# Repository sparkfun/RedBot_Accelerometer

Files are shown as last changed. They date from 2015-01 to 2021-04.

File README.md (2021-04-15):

RedBot Accelerometer
==================
SparkFun RedBot Accelerometer (https://www.sparkfun.com/products/12589)

[*SparkFun RedBot Accelerometer*](https://www.sparkfun.com/products/12589)

The accelerometer sensor is an add-on for the RedBot kit that provides bump and motion detection. 
It is an I<sup>2</sup>C, and is a 3-axis sensor.

Repository Contents
-------------------

* **/Hardware** - Eagle PCB layout files
* **/Production** - Pogo testbed files

Documentation
-------------------
* **[Assembly Guide for RedBot with Shadow Chassis](https://learn.sparkfun.com/tutorials/assembly-guide-for-redbot-with-shadow-chassis)**
* **[Experiment Guide for RedBot with Shadow Chassis](https://learn.sparkfun.com/tutorials/experiment-guide-for-redbot-with-shadow-chassis)**

License Information
-------------------

The hardware is released under [Creative Commons ShareAlike 4.0 International](https://creativecommons.org/licenses/by-sa/4.0/).
The code is beerware; if you see me (or any other SparkFun employee) at the local, and you've found our code helpful, please buy us a round!

Distributed as-is; no warranty is given.

Authors: Mike Hord @ SparkFun Electonics

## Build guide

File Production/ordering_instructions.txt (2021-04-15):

panel size, 115x171mm
PCB thickness, 1.6mm
number of layers, 2
soldermask color, Red
silkscreen color, White
oz copper, 1oz
finish, HASL lead free
stencils, top
pcs per panel, 63
min trace width, 0.1778mm / 0.0070in
min drill size, 0.3810mm / 0.0150in

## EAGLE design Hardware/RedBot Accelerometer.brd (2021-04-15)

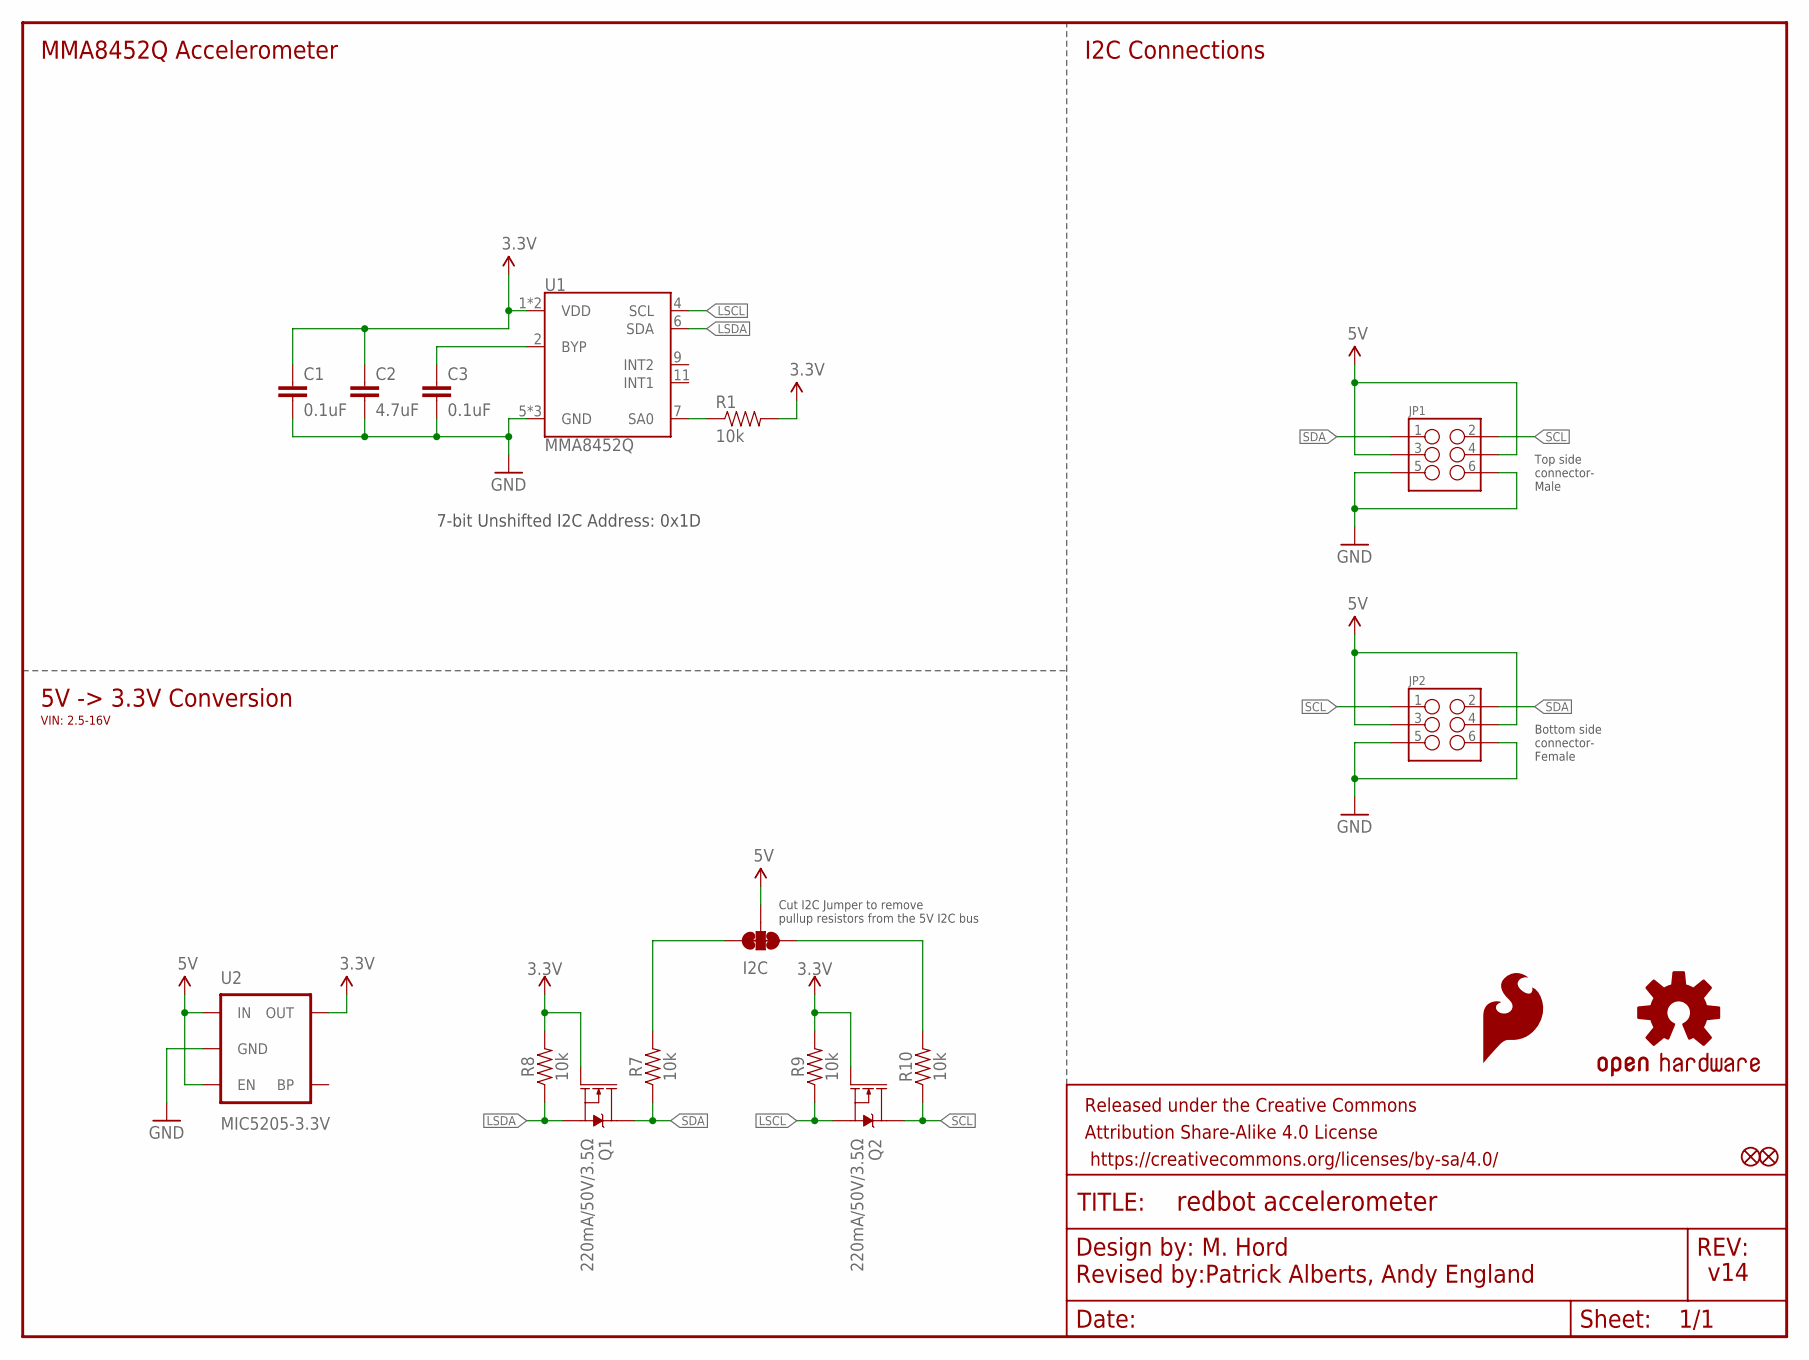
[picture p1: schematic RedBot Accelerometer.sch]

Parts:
C1, C3: 0.1uF; 0603
C2: 4.7uF; 0603
FID1, FID3: FIDUCIAL1X2; FIDUCIAL-1X2
FRAME1: FRAME-LETTER; CREATIVE_COMMONS
I2C: JUMPER-SMT_3_2-NC_TRACE_SILK; SMT-JUMPER_3_2-NC_TRACE_SILK
JP1: M03X2SMT; 2X3_SMT_POSTS
JP2: M03X2FEMALE_SMD; 2X3_SMD
LOGO2: OSHW-LOGOS; OSHW-LOGO-S
LOGO4: SFE_LOGO_FLAME.1_INCH; SFE_LOGO_FLAME_.1
Q1, Q2: 220mA/50V/3.5Ω; SOT23-3
R1, R7, R8, R9, R10: 10k; 0603
U1: MMA8452Q; QFN-16
U2: MIC5205-3.3V; SOT23-5

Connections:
3.3V: C1.1, C2.1, Q1.1 (G), Q2.1 (G), R1.2, R8.2, R9.2, U1.1 (VDD), U1.14 (VDD), U2.5 (OUT)
5V: I2C.2, JP1.3, JP1.4, JP2.3, JP2.4, U2.1 (IN), U2.3 (EN)
ADDR: R1.1, U1.7 (SA0)
GND: C1.2, C2.2, C3.2, JP1.5, JP1.6, JP2.5, JP2.6, U1.5 (GND), U1.10 (GND), U1.12 (GND), U2.2 (GND)
LSCL: Q2.2 (S), R9.1, U1.4 (SCL)
LSDA: Q1.2 (S), R8.1, U1.6 (SDA)
unnamed: C3.1, U1.2 (BYP)
unnamed: I2C.3, R7.2
unnamed: I2C.1, R10.2
SCL: JP1.2, JP2.1, Q2.3 (D), R10.1
SDA: JP1.1, JP2.2, Q1.3 (D), R7.1

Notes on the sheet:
v14
M. Hord
Top side connector- Male
Bottom side connector- Female
Revised by:Patrick Alberts, Andy England
Cut I2C Jumper to remove pullup resistors from the 5V I2C bus
5V -> 3.3V Conversion
MMA8452Q Accelerometer
I2C Connections
VIN: 2.5-16V
7-bit Unshifted I2C Address: 0x1D

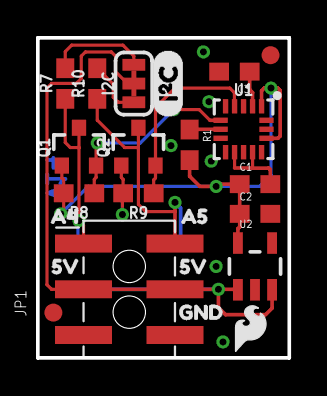
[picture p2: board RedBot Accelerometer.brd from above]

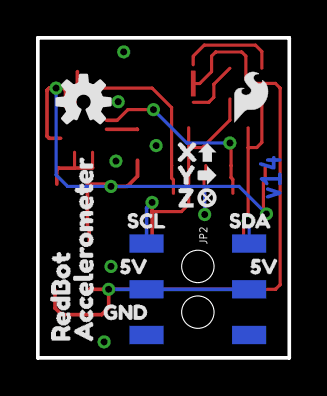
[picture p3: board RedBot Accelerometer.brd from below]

Board: 2 copper layers, 14.0 x 17.8 mm, 39 parts (15 on the bottom side), 11 nets.

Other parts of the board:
LOGO3: LOGO-SFESK; SFE-LOGO-FLAME
U$1: X0
U$2: A42
U$3: A53
U$4, U$5, U$8, U$11: _5V1
U$6, U$7: GND0
U$9: SDA6
U$10: _SCL7
U$12: ##3
U$13: ##4
U$14: Y1
U$15: Z2
U$16: REDBOT4
U$17: ACCELEROMETER5
U$19: I2C

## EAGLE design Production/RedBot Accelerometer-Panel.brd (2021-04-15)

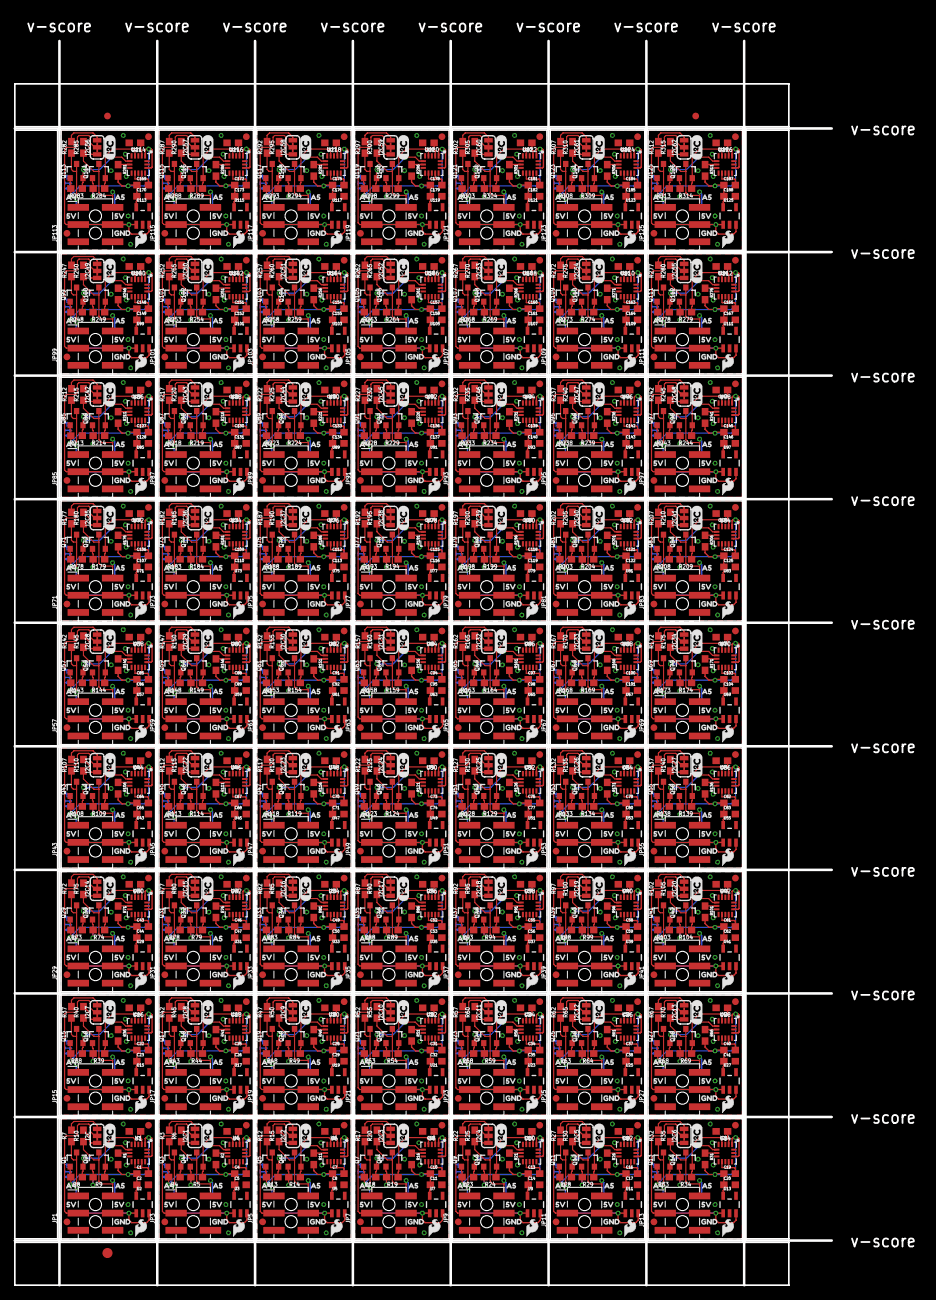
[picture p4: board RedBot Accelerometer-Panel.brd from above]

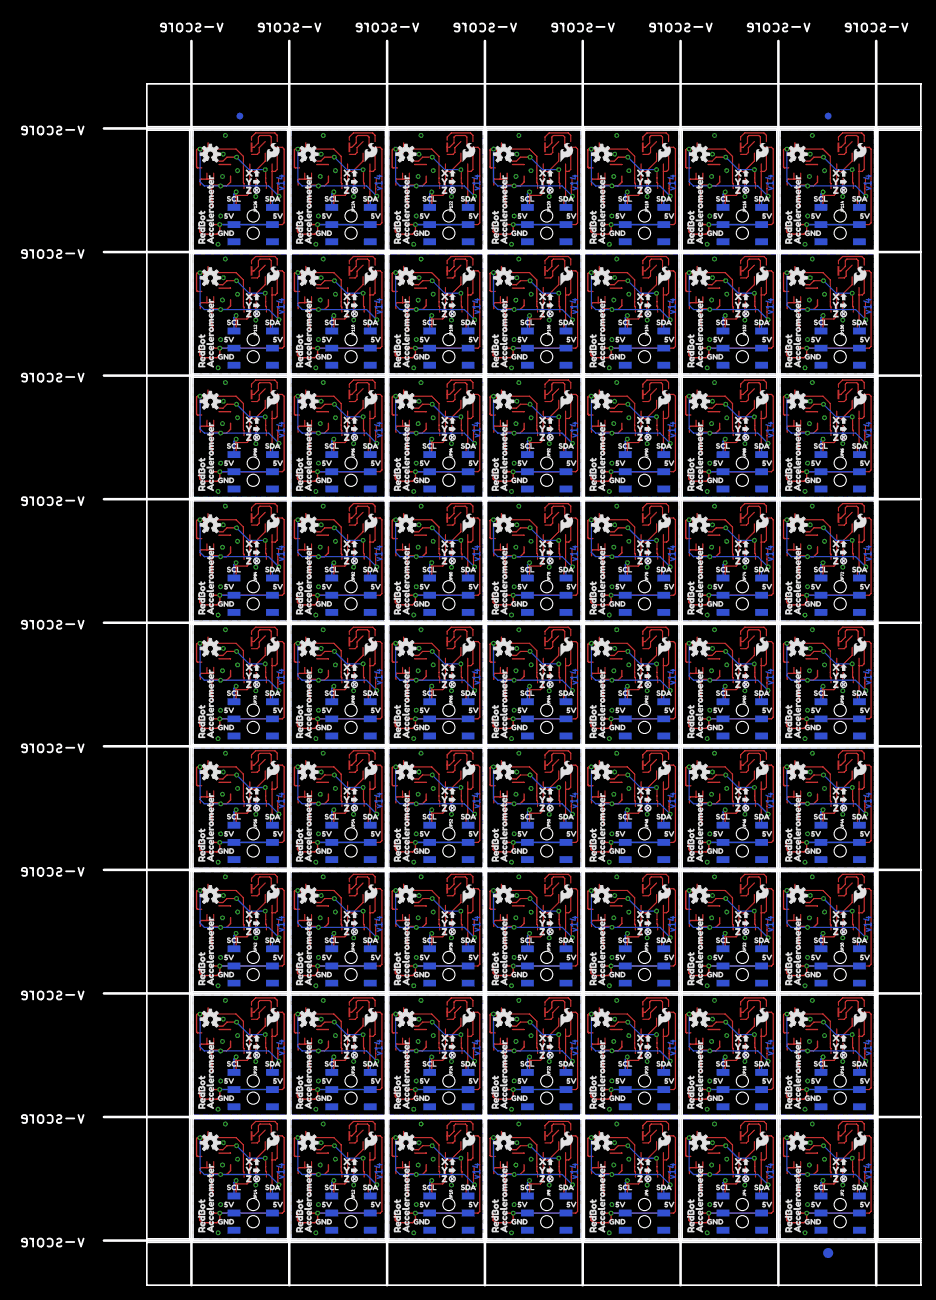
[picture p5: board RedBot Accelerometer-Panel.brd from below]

Board: 2 copper layers, 120.9 x 184.2 mm, 2400 parts (948 on the bottom side), 693 nets.

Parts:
C1, C3, C4, C6, C7, C9, C10, C12, C13, C15, C16, C18, C19, C21, C22, C24, C25, C27, C28, C30, C31, C33, C34, C36, C37, C39, C40, C42, C43, C45, C46, C48, C49, C51, C52, C54, C55, C57, C58, C60, C61, C63, C64, C66, C67, C69, C70, C72, C73, C75, C76, C78, C79, C81, C82, C84, C85, C87, C88, C90, C91, C93, C94, C96, C97, C99, C100, C102, C103, C105, C106, C108, C109, C111, C112, C114, C115, C117, C118, C120, C121, C123, C124, C126, C127, C129, C130, C132, C133, C135, C136, C138, C139, C141, C142, C144, C145, C147, C148, C150, C151, C153, C154, C156, C157, C159, C160, C162, C163, C165, C166, C168, C169, C171, C172, C174, C175, C177, C178, C180, C181, C183, C184, C186, C187, C189: 0.1uF; 0603
C2, C5, C8, C11, C14, C17, C20, C23, C26, C29, C32, C35, C38, C41, C44, C47, C50, C53, C56, C59, C62, C65, C68, C71, C74, C77, C80, C83, C86, C89, C92, C95, C98, C101, C104, C107, C110, C113, C116, C119, C122, C125, C128, C131, C134, C137, C140, C143, C146, C149, C152, C155, C158, C161, C164, C167, C170, C173, C176, C179, C182, C185, C188: 4.7uF; 0603
E$1, E$2, E$3, E$4: FIDUCIAL-1X2
E$5, E$6: FIDUCIAL-1.5X3
FID1, FID2, FID3, FID4, FID5, FID6, FID7, FID8, FID9, FID10, FID11, FID12, FID13, FID14, FID15, FID16, FID17, FID18, FID19, FID20, FID21, FID22, FID23, FID24, FID25, FID26, FID27, FID28, FID29, FID30, FID31, FID32, FID33, FID34, FID35, FID36, FID37, FID38, FID39, FID40, FID41, FID42, FID43, FID44, FID45, FID46, FID47, FID48, FID49, FID50, FID51, FID52, FID53, FID54, FID55, FID56, FID57, FID58, FID59, FID60, FID61, FID62, FID63, FID64, FID65, FID66, FID67, FID68, FID69, FID70, FID71, FID72, FID73, FID74, FID75, FID76, FID77, FID78, FID79, FID80, FID81, FID82, FID83, FID84, FID85, FID86, FID87, FID88, FID89, FID90, FID91, FID92, FID93, FID94, FID95, FID96, FID97, FID98, FID99, FID100, FID101, FID102, FID103, FID104, FID105, FID106, FID107, FID108, FID109, FID110, FID111, FID112, FID113, FID114, FID115, FID116, FID117, FID118, FID119, FID120, FID121, FID122, FID123, FID124, FID125, FID126: FIDUCIAL1X2; FIDUCIAL-1X2
I2C, I2C1, I2C2, I2C3, I2C4, I2C5, I2C6, I2C7, I2C8, I2C9, I2C10, I2C11, I2C12, I2C13, I2C14, I2C15, I2C16, I2C17, I2C18, I2C19, I2C20, I2C21, I2C22, I2C23, I2C24, I2C25, I2C26, I2C27, I2C28, I2C29, I2C30, I2C31, I2C32, I2C33, I2C34, I2C35, I2C36, I2C37, I2C38, I2C39, I2C40, I2C41, I2C42, I2C43, I2C44, I2C45, I2C46, I2C47, I2C48, I2C49, I2C50, I2C51, I2C52, I2C53, I2C54, I2C55, I2C56, I2C57, I2C58, I2C59, I2C60, I2C61, I2C62: JUMPER-SMT_3_2-NC_TRACE_SILK; SMT-JUMPER_3_2-NC_TRACE_SILK
JP1, JP3, JP5, JP7, JP9, JP11, JP13, JP15, JP17, JP19, JP21, JP23, JP25, JP27, JP29, JP31, JP33, JP35, JP37, JP39, JP41, JP43, JP45, JP47, JP49, JP51, JP53, JP55, JP57, JP59, JP61, JP63, JP65, JP67, JP69, JP71, JP73, JP75, JP77, JP79, JP81, JP83, JP85, JP87, JP89, JP91, JP93, JP95, JP97, JP99, JP101, JP103, JP105, JP107, JP109, JP111, JP113, JP115, JP117, JP119, JP121, JP123, JP125: 2X3_SMT_POSTS
JP2, JP4, JP6, JP8, JP10, JP12, JP14, JP16, JP18, JP20, JP22, JP24, JP26, JP28, JP30, JP32, JP34, JP36, JP38, JP40, JP42, JP44, JP46, JP48, JP50, JP52, JP54, JP56, JP58, JP60, JP62, JP64, JP66, JP68, JP70, JP72, JP74, JP76, JP78, JP80, JP82, JP84, JP86, JP88, JP90, JP92, JP94, JP96, JP98, JP100, JP102, JP104, JP106, JP108, JP110, JP112, JP114, JP116, JP118, JP120, JP122, JP124, JP126: 2X3_SMD
LOGO1, LOGO2, LOGO7, LOGO10, LOGO13, LOGO16, LOGO19, LOGO22, LOGO25, LOGO28, LOGO31, LOGO34, LOGO37, LOGO40, LOGO43, LOGO46, LOGO49, LOGO52, LOGO55, LOGO58, LOGO61, LOGO64, LOGO67, LOGO70, LOGO73, LOGO76, LOGO79, LOGO82, LOGO85, LOGO88, LOGO91, LOGO94, LOGO97, LOGO100, LOGO103, LOGO106, LOGO109, LOGO112, LOGO115, LOGO118, LOGO121, LOGO124, LOGO127, LOGO130, LOGO133, LOGO136, LOGO139, LOGO142, LOGO145, LOGO148, LOGO151, LOGO154, LOGO157, LOGO160, LOGO163, LOGO166, LOGO169, LOGO172, LOGO175, LOGO178, LOGO181, LOGO184, LOGO187: OSHW-LOGOS; OSHW-LOGO-S
LOGO3, LOGO5, LOGO8, LOGO11, LOGO14, LOGO17, LOGO20, LOGO23, LOGO26, LOGO29, LOGO32, LOGO35, LOGO38, LOGO41, LOGO44, LOGO47, LOGO50, LOGO53, LOGO56, LOGO59, LOGO62, LOGO65, LOGO68, LOGO71, LOGO74, LOGO77, LOGO80, LOGO83, LOGO86, LOGO89, LOGO92, LOGO95, LOGO98, LOGO101, LOGO104, LOGO107, LOGO110, LOGO113, LOGO116, LOGO119, LOGO122, LOGO125, LOGO128, LOGO131, LOGO134, LOGO137, LOGO140, LOGO143, LOGO146, LOGO149, LOGO152, LOGO155, LOGO158, LOGO161, LOGO164, LOGO167, LOGO170, LOGO173, LOGO176, LOGO179, LOGO182, LOGO185, LOGO188: LOGO-SFESK; SFE-LOGO-FLAME
LOGO4, LOGO6, LOGO9, LOGO12, LOGO15, LOGO18, LOGO21, LOGO24, LOGO27, LOGO30, LOGO33, LOGO36, LOGO39, LOGO42, LOGO45, LOGO48, LOGO51, LOGO54, LOGO57, LOGO60, LOGO63, LOGO66, LOGO69, LOGO72, LOGO75, LOGO78, LOGO81, LOGO84, LOGO87, LOGO90, LOGO93, LOGO96, LOGO99, LOGO102, LOGO105, LOGO108, LOGO111, LOGO114, LOGO117, LOGO120, LOGO123, LOGO126, LOGO129, LOGO132, LOGO135, LOGO138, LOGO141, LOGO144, LOGO147, LOGO150, LOGO153, LOGO156, LOGO159, LOGO162, LOGO165, LOGO168, LOGO171, LOGO174, LOGO177, LOGO180, LOGO183, LOGO186, LOGO189: SFE_LOGO_FLAME.1_INCH; SFE_LOGO_FLAME_.1
Q1, Q2, Q3, Q4, Q5, Q6, Q7, Q8, Q9, Q10, Q11, Q12, Q13, Q14, Q15, Q16, Q17, Q18, Q19, Q20, Q21, Q22, Q23, Q24, Q25, Q26, Q27, Q28, Q29, Q30, Q31, Q32, Q33, Q34, Q35, Q36, Q37, Q38, Q39, Q40, Q41, Q42, Q43, Q44, Q45, Q46, Q47, Q48, Q49, Q50, Q51, Q52, Q53, Q54, Q55, Q56, Q57, Q58, Q59, Q60, Q61, Q62, Q63, Q64, Q65, Q66, Q67, Q68, Q69, Q70, Q71, Q72, Q73, Q74, Q75, Q76, Q77, Q78, Q79, Q80, Q81, Q82, Q83, Q84, Q85, Q86, Q87, Q88, Q89, Q90, Q91, Q92, Q93, Q94, Q95, Q96, Q97, Q98, Q99, Q100, Q101, Q102, Q103, Q104, Q105, Q106, Q107, Q108, Q109, Q110, Q111, Q112, Q113, Q114, Q115, Q116, Q117, Q118, Q119, Q120, Q121, Q122, Q123, Q124, Q125, Q126: 220mA/50V/3.5Ω; SOT23-3
R1, R2, R3, R4, R5, R6, R7, R8, R9, R10, R11, R12, R13, R14, R15, R16, R17, R18, R19, R20, R21, R22, R23, R24, R25, R26, R27, R28, R29, R30, R31, R32, R33, R34, R35, R36, R37, R38, R39, R40, R41, R42, R43, R44, R45, R46, R47, R48, R49, R50, R51, R52, R53, R54, R55, R56, R57, R58, R59, R60, R61, R62, R63, R64, R65, R66, R67, R68, R69, R70, R71, R72, R73, R74, R75, R76, R77, R78, R79, R80, R81, R82, R83, R84, R85, R86, R87, R88, R89, R90, R91, R92, R93, R94, R95, R96, R97, R98, R99, R100, R101, R102, R103, R104, R105, R106, R107, R108, R109, R110, R111, R112, R113, R114, R115, R116, R117, R118, R119, R120, R121, R122, R123, R124, R125, R126, R127, R128, R129, R130, R131, R132, R133, R134, R135, R136, R137, R138, R139, R140, R141, R142, R143, R144, R145, R146, R147, R148, R149, R150, R151, R152, R153, R154, R155, R156, R157, R158, R159, R160, R161, R162, R163, R164, R165, R166, R167, R168, R169, R170, R171, R172, R173, R174, R175, R176, R177, R178, R179, R180, R181, R182, R183, R184, R185, R186, R187, R188, R189, R190, R191, R192, R193, R194, R195, R196, R197, R198, R199, R200, R201, R202, R203, R204, R205, R206, R207, R208, R209, R210, R211, R212, R213, R214, R215, R216, R217, R218, R219, R220, R221, R222, R223, R224, R225, R226, R227, R228, R229, R230, R231, R232, R233, R234, R235, R236, R237, R238, R239, R240, R241, R242, R243, R244, R245, R246, R247, R248, R249, R250, R251, R252, R253, R254, R255, R256, R257, R258, R259, R260, R261, R262, R263, R264, R265, R266, R267, R268, R269, R270, R271, R272, R273, R274, R275, R276, R277, R278, R279, R280, R281, R282, R283, R284, R285, R286, R287, R288, R289, R290, R291, R292, R293, R294, R295, R296, R297, R298, R299, R300, R301, R302, R303, R304, R305, R306, R307, R308, R309, R310, R311, R312, R313, R314, R315: 10k; 0603
U1, U4, U6, U8, U10, U12, U14, U16, U18, U20, U22, U24, U26, U28, U30, U32, U34, U36, U38, U40, U42, U44, U46, U48, U50, U52, U54, U56, U58, U60, U62, U64, U66, U68, U70, U72, U74, U76, U78, U80, U82, U84, U86, U88, U90, U92, U94, U96, U98, U100, U102, U104, U106, U108, U110, U112, U114, U116, U118, U120, U122, U124, U126: MMA8452Q; QFN-16
U2, U3, U5, U7, U9, U11, U13, U15, U17, U19, U21, U23, U25, U27, U29, U31, U33, U35, U37, U39, U41, U43, U45, U47, U49, U51, U53, U55, U57, U59, U61, U63, U65, U67, U69, U71, U73, U75, U77, U79, U81, U83, U85, U87, U89, U91, U93, U95, U97, U99, U101, U103, U105, U107, U109, U111, U113, U115, U117, U119, U121, U123, U125: MIC5205-3.3V; SOT23-5
U$1, U$18, U$37, U$55, U$73, U$91, U$109, U$127, U$145, U$163, U$181, U$199, U$217, U$235, U$253, U$271, U$289, U$307, U$325, U$343, U$361, U$379, U$397, U$415, U$433, U$451, U$469, U$487, U$505, U$523, U$541, U$559, U$577, U$595, U$613, U$631, U$649, U$667, U$685, U$703, U$721, U$739, U$757, U$775, U$793, U$811, U$829, U$847, U$865, U$883, U$901, U$919, U$937, U$955, U$973, U$991, U$1009, U$1027, U$1045, U$1063, U$1081, U$1099, U$1117: X0
U$2, U$20, U$38, U$56, U$74, U$92, U$110, U$128, U$146, U$164, U$182, U$200, U$218, U$236, U$254, U$272, U$290, U$308, U$326, U$344, U$362, U$380, U$398, U$416, U$434, U$452, U$470, U$488, U$506, U$524, U$542, U$560, U$578, U$596, U$614, U$632, U$650, U$668, U$686, U$704, U$722, U$740, U$758, U$776, U$794, U$812, U$830, U$848, U$866, U$884, U$902, U$920, U$938, U$956, U$974, U$992, U$1010, U$1028, U$1046, U$1064, U$1082, U$1100, U$1118: A42
U$3, U$21, U$39, U$57, U$75, U$93, U$111, U$129, U$147, U$165, U$183, U$201, U$219, U$237, U$255, U$273, U$291, U$309, U$327, U$345, U$363, U$381, U$399, U$417, U$435, U$453, U$471, U$489, U$507, U$525, U$543, U$561, U$579, U$597, U$615, U$633, U$651, U$669, U$687, U$705, U$723, U$741, U$759, U$777, U$795, U$813, U$831, U$849, U$867, U$885, U$903, U$921, U$939, U$957, U$975, U$993, U$1011, U$1029, U$1047, U$1065, U$1083, U$1101, U$1119: A53
U$4, U$5, U$8, U$11, U$22, U$23, U$26, U$29, U$40, U$41, U$44, U$47, U$58, U$59, U$62, U$65, U$76, U$77, U$80, U$83, U$94, U$95, U$98, U$101, U$112, U$113, U$116, U$119, U$130, U$131, U$134, U$137, U$148, U$149, U$152, U$155, U$166, U$167, U$170, U$173, U$184, U$185, U$188, U$191, U$202, U$203, U$206, U$209, U$220, U$221, U$224, U$227, U$238, U$239, U$242, U$245, U$256, U$257, U$260, U$263, U$274, U$275, U$278, U$281, U$292, U$293, U$296, U$299, U$310, U$311, U$314, U$317, U$328, U$329, U$332, U$335, U$346, U$347, U$350, U$353, U$364, U$365, U$368, U$371, U$382, U$383, U$386, U$389, U$400, U$401, U$404, U$407, U$418, U$419, U$422, U$425, U$436, U$437, U$440, U$443, U$454, U$455, U$458, U$461, U$472, U$473, U$476, U$479, U$490, U$491, U$494, U$497, U$508, U$509, U$512, U$515, U$526, U$527, U$530, U$533, U$544, U$545, U$548, U$551, U$562, U$563, U$566, U$569, U$580, U$581, U$584, U$587, U$598, U$599, U$602, U$605, U$616, U$617, U$620, U$623, U$634, U$635, U$638, U$641, U$652, U$653, U$656, U$659, U$670, U$671, U$674, U$677, U$688, U$689, U$692, U$695, U$706, U$707, U$710, U$713, U$724, U$725, U$728, U$731, U$742, U$743, U$746, U$749, U$760, U$761, U$764, U$767, U$778, U$779, U$782, U$785, U$796, U$797, U$800, U$803, U$814, U$815, U$818, U$821, U$832, U$833, U$836, U$839, U$850, U$851, U$854, U$857, U$868, U$869, U$872, U$875, U$886, U$887, U$890, U$893, U$904, U$905, U$908, U$911, U$922, U$923, U$926, U$929, U$940, U$941, U$944, U$947, U$958, U$959, U$962, U$965, U$976, U$977, U$980, U$983, U$994, U$995, U$998, U$1001, U$1012, U$1013, U$1016, U$1019, U$1030, U$1031, U$1034, U$1037, U$1048, U$1049, U$1052, U$1055, U$1066, U$1067, U$1070, U$1073, U$1084, U$1085, U$1088, U$1091, U$1102, U$1103, U$1106, U$1109, U$1120, U$1121, U$1124, U$1127: _5V1
U$6, U$7, U$24, U$25, U$42, U$43, U$60, U$61, U$78, U$79, U$96, U$97, U$114, U$115, U$132, U$133, U$150, U$151, U$168, U$169, U$186, U$187, U$204, U$205, U$222, U$223, U$240, U$241, U$258, U$259, U$276, U$277, U$294, U$295, U$312, U$313, U$330, U$331, U$348, U$349, U$366, U$367, U$384, U$385, U$402, U$403, U$420, U$421, U$438, U$439, U$456, U$457, U$474, U$475, U$492, U$493, U$510, U$511, U$528, U$529, U$546, U$547, U$564, U$565, U$582, U$583, U$600, U$601, U$618, U$619, U$636, U$637, U$654, U$655, U$672, U$673, U$690, U$691, U$708, U$709, U$726, U$727, U$744, U$745, U$762, U$763, U$780, U$781, U$798, U$799, U$816, U$817, U$834, U$835, U$852, U$853, U$870, U$871, U$888, U$889, U$906, U$907, U$924, U$925, U$942, U$943, U$960, U$961, U$978, U$979, U$996, U$997, U$1014, U$1015, U$1032, U$1033, U$1050, U$1051, U$1068, U$1069, U$1086, U$1087, U$1104, U$1105, U$1122, U$1123: GND0
U$9, U$27, U$45, U$63, U$81, U$99, U$117, U$135, U$153, U$171, U$189, U$207, U$225, U$243, U$261, U$279, U$297, U$315, U$333, U$351, U$369, U$387, U$405, U$423, U$441, U$459, U$477, U$495, U$513, U$531, U$549, U$567, U$585, U$603, U$621, U$639, U$657, U$675, U$693, U$711, U$729, U$747, U$765, U$783, U$801, U$819, U$837, U$855, U$873, U$891, U$909, U$927, U$945, U$963, U$981, U$999, U$1017, U$1035, U$1053, U$1071, U$1089, U$1107, U$1125: SDA6
U$10, U$28, U$46, U$64, U$82, U$100, U$118, U$136, U$154, U$172, U$190, U$208, U$226, U$244, U$262, U$280, U$298, U$316, U$334, U$352, U$370, U$388, U$406, U$424, U$442, U$460, U$478, U$496, U$514, U$532, U$550, U$568, U$586, U$604, U$622, U$640, U$658, U$676, U$694, U$712, U$730, U$748, U$766, U$784, U$802, U$820, U$838, U$856, U$874, U$892, U$910, U$928, U$946, U$964, U$982, U$1000, U$1018, U$1036, U$1054, U$1072, U$1090, U$1108, U$1126: _SCL7
U$12, U$30, U$48, U$66, U$84, U$102, U$120, U$138, U$156, U$174, U$192, U$210, U$228, U$246, U$264, U$282, U$300, U$318, U$336, U$354, U$372, U$390, U$408, U$426, U$444, U$462, U$480, U$498, U$516, U$534, U$552, U$570, U$588, U$606, U$624, U$642, U$660, U$678, U$696, U$714, U$732, U$750, U$768, U$786, U$804, U$822, U$840, U$858, U$876, U$894, U$912, U$930, U$948, U$966, U$984, U$1002, U$1020, U$1038, U$1056, U$1074, U$1092, U$1110, U$1128: ##3
U$13, U$31, U$49, U$67, U$85, U$103, U$121, U$139, U$157, U$175, U$193, U$211, U$229, U$247, U$265, U$283, U$301, U$319, U$337, U$355, U$373, U$391, U$409, U$427, U$445, U$463, U$481, U$499, U$517, U$535, U$553, U$571, U$589, U$607, U$625, U$643, U$661, U$679, U$697, U$715, U$733, U$751, U$769, U$787, U$805, U$823, U$841, U$859, U$877, U$895, U$913, U$931, U$949, U$967, U$985, U$1003, U$1021, U$1039, U$1057, U$1075, U$1093, U$1111, U$1129: ##4
U$14, U$32, U$50, U$68, U$86, U$104, U$122, U$140, U$158, U$176, U$194, U$212, U$230, U$248, U$266, U$284, U$302, U$320, U$338, U$356, U$374, U$392, U$410, U$428, U$446, U$464, U$482, U$500, U$518, U$536, U$554, U$572, U$590, U$608, U$626, U$644, U$662, U$680, U$698, U$716, U$734, U$752, U$770, U$788, U$806, U$824, U$842, U$860, U$878, U$896, U$914, U$932, U$950, U$968, U$986, U$1004, U$1022, U$1040, U$1058, U$1076, U$1094, U$1112, U$1130: Y1
U$15, U$33, U$51, U$69, U$87, U$105, U$123, U$141, U$159, U$177, U$195, U$213, U$231, U$249, U$267, U$285, U$303, U$321, U$339, U$357, U$375, U$393, U$411, U$429, U$447, U$465, U$483, U$501, U$519, U$537, U$555, U$573, U$591, U$609, U$627, U$645, U$663, U$681, U$699, U$717, U$735, U$753, U$771, U$789, U$807, U$825, U$843, U$861, U$879, U$897, U$915, U$933, U$951, U$969, U$987, U$1005, U$1023, U$1041, U$1059, U$1077, U$1095, U$1113, U$1131: Z2
U$16, U$34, U$52, U$70, U$88, U$106, U$124, U$142, U$160, U$178, U$196, U$214, U$232, U$250, U$268, U$286, U$304, U$322, U$340, U$358, U$376, U$394, U$412, U$430, U$448, U$466, U$484, U$502, U$520, U$538, U$556, U$574, U$592, U$610, U$628, U$646, U$664, U$682, U$700, U$718, U$736, U$754, U$772, U$790, U$808, U$826, U$844, U$862, U$880, U$898, U$916, U$934, U$952, U$970, U$988, U$1006, U$1024, U$1042, U$1060, U$1078, U$1096, U$1114, U$1132: REDBOT4
U$17, U$35, U$53, U$71, U$89, U$107, U$125, U$143, U$161, U$179, U$197, U$215, U$233, U$251, U$269, U$287, U$305, U$323, U$341, U$359, U$377, U$395, U$413, U$431, U$449, U$467, U$485, U$503, U$521, U$539, U$557, U$575, U$593, U$611, U$629, U$647, U$665, U$683, U$701, U$719, U$737, U$755, U$773, U$791, U$809, U$827, U$845, U$863, U$881, U$899, U$917, U$935, U$953, U$971, U$989, U$1007, U$1025, U$1043, U$1061, U$1079, U$1097, U$1115, U$1133: ACCELEROMETER5
U$19, U$36, U$54, U$72, U$90, U$108, U$126, U$144, U$162, U$180, U$198, U$216, U$234, U$252, U$270, U$288, U$306, U$324, U$342, U$360, U$378, U$396, U$414, U$432, U$450, U$468, U$486, U$504, U$522, U$540, U$558, U$576, U$594, U$612, U$630, U$648, U$666, U$684, U$702, U$720, U$738, U$756, U$774, U$792, U$810, U$828, U$846, U$864, U$882, U$900, U$918, U$936, U$954, U$972, U$990, U$1008, U$1026, U$1044, U$1062, U$1080, U$1098, U$1116, U$1134: I2C

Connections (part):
3.3V: C1.1, C2.1, Q1.1, Q2.1, R1.2, R8.2, R9.2, U1.1, U1.14, U2.5
3.3V1: C4.1, C5.1, Q3.1, Q4.1, R2.2, R4.2, R5.2, U3.5, U4.1, U4.14
3.3V2: C7.1, C8.1, Q5.1, Q6.1, R11.2, R13.2, R14.2, U5.5, U6.1, U6.14
3.3V3: C10.1, C11.1, Q7.1, Q8.1, R16.2, R18.2, R19.2, U7.5, U8.1, U8.14
3.3V4: C13.1, C14.1, Q9.1, Q10.1, R21.2, R23.2, R24.2, U9.5, U10.1, U10.14
3.3V5: C16.1, C17.1, Q11.1, Q12.1, R26.2, R28.2, R29.2, U11.5, U12.1, U12.14
3.3V6: C19.1, C20.1, Q13.1, Q14.1, R31.2, R33.2, R34.2, U13.5, U14.1, U14.14
3.3V7: C22.1, C23.1, Q15.1, Q16.1, R36.2, R38.2, R39.2, U15.5, U16.1, U16.14
3.3V8: C25.1, C26.1, Q17.1, Q18.1, R41.2, R43.2, R44.2, U17.5, U18.1, U18.14
3.3V9: C28.1, C29.1, Q19.1, Q20.1, R46.2, R48.2, R49.2, U19.5, U20.1, U20.14
3.3V10: C31.1, C32.1, Q21.1, Q22.1, R51.2, R53.2, R54.2, U21.5, U22.1, U22.14
3.3V11: C34.1, C35.1, Q23.1, Q24.1, R56.2, R58.2, R59.2, U23.5, U24.1, U24.14
3.3V12: C37.1, C38.1, Q25.1, Q26.1, R61.2, R63.2, R64.2, U25.5, U26.1, U26.14
3.3V13: C40.1, C41.1, Q27.1, Q28.1, R66.2, R68.2, R69.2, U27.5, U28.1, U28.14
3.3V14: C43.1, C44.1, Q29.1, Q30.1, R71.2, R73.2, R74.2, U29.5, U30.1, U30.14
3.3V15: C46.1, C47.1, Q31.1, Q32.1, R76.2, R78.2, R79.2, U31.5, U32.1, U32.14
3.3V16: C49.1, C50.1, Q33.1, Q34.1, R81.2, R83.2, R84.2, U33.5, U34.1, U34.14
3.3V17: C52.1, C53.1, Q35.1, Q36.1, R86.2, R88.2, R89.2, U35.5, U36.1, U36.14
3.3V18: C55.1, C56.1, Q37.1, Q38.1, R91.2, R93.2, R94.2, U37.5, U38.1, U38.14
3.3V19: C58.1, C59.1, Q39.1, Q40.1, R96.2, R98.2, R99.2, U39.5, U40.1, U40.14
3.3V20: C61.1, C62.1, Q41.1, Q42.1, R101.2, R103.2, R104.2, U41.5, U42.1, U42.14
3.3V21: C64.1, C65.1, Q43.1, Q44.1, R106.2, R108.2, R109.2, U43.5, U44.1, U44.14
3.3V22: C67.1, C68.1, Q45.1, Q46.1, R111.2, R113.2, R114.2, U45.5, U46.1, U46.14
3.3V23: C70.1, C71.1, Q47.1, Q48.1, R116.2, R118.2, R119.2, U47.5, U48.1, U48.14
3.3V24: C73.1, C74.1, Q49.1, Q50.1, R121.2, R123.2, R124.2, U49.5, U50.1, U50.14
3.3V25: C76.1, C77.1, Q51.1, Q52.1, R126.2, R128.2, R129.2, U51.5, U52.1, U52.14
3.3V26: C79.1, C80.1, Q53.1, Q54.1, R131.2, R133.2, R134.2, U53.5, U54.1, U54.14
3.3V27: C82.1, C83.1, Q55.1, Q56.1, R136.2, R138.2, R139.2, U55.5, U56.1, U56.14
3.3V28: C85.1, C86.1, Q57.1, Q58.1, R141.2, R143.2, R144.2, U57.5, U58.1, U58.14
3.3V29: C88.1, C89.1, Q59.1, Q60.1, R146.2, R148.2, R149.2, U59.5, U60.1, U60.14
3.3V30: C91.1, C92.1, Q61.1, Q62.1, R151.2, R153.2, R154.2, U61.5, U62.1, U62.14
3.3V31: C94.1, C95.1, Q63.1, Q64.1, R156.2, R158.2, R159.2, U63.5, U64.1, U64.14
3.3V32: C97.1, C98.1, Q65.1, Q66.1, R161.2, R163.2, R164.2, U65.5, U66.1, U66.14
3.3V33: C100.1, C101.1, Q67.1, Q68.1, R166.2, R168.2, R169.2, U67.5, U68.1, U68.14
3.3V34: C103.1, C104.1, Q69.1, Q70.1, R171.2, R173.2, R174.2, U69.5, U70.1, U70.14
3.3V35: C106.1, C107.1, Q71.1, Q72.1, R176.2, R178.2, R179.2, U71.5, U72.1, U72.14
3.3V36: C109.1, C110.1, Q73.1, Q74.1, R181.2, R183.2, R184.2, U73.5, U74.1, U74.14
3.3V37: C112.1, C113.1, Q75.1, Q76.1, R186.2, R188.2, R189.2, U75.5, U76.1, U76.14
3.3V38: C115.1, C116.1, Q77.1, Q78.1, R191.2, R193.2, R194.2, U77.5, U78.1, U78.14
3.3V39: C118.1, C119.1, Q79.1, Q80.1, R196.2, R198.2, R199.2, U79.5, U80.1, U80.14
3.3V40: C121.1, C122.1, Q81.1, Q82.1, R201.2, R203.2, R204.2, U81.5, U82.1, U82.14
3.3V41: C124.1, C125.1, Q83.1, Q84.1, R206.2, R208.2, R209.2, U83.5, U84.1, U84.14
3.3V42: C127.1, C128.1, Q85.1, Q86.1, R211.2, R213.2, R214.2, U85.5, U86.1, U86.14
3.3V43: C130.1, C131.1, Q87.1, Q88.1, R216.2, R218.2, R219.2, U87.5, U88.1, U88.14
3.3V44: C133.1, C134.1, Q89.1, Q90.1, R221.2, R223.2, R224.2, U89.5, U90.1, U90.14
3.3V45: C136.1, C137.1, Q91.1, Q92.1, R226.2, R228.2, R229.2, U91.5, U92.1, U92.14
3.3V46: C139.1, C140.1, Q93.1, Q94.1, R231.2, R233.2, R234.2, U93.5, U94.1, U94.14
3.3V47: C142.1, C143.1, Q95.1, Q96.1, R236.2, R238.2, R239.2, U95.5, U96.1, U96.14
3.3V48: C145.1, C146.1, Q97.1, Q98.1, R241.2, R243.2, R244.2, U97.5, U98.1, U98.14
3.3V49: C148.1, C149.1, Q99.1, Q100.1, R246.2, R248.2, R249.2, U99.5, U100.1, U100.14
3.3V50: C151.1, C152.1, Q101.1, Q102.1, R251.2, R253.2, R254.2, U101.5, U102.1, U102.14
3.3V51: C154.1, C155.1, Q103.1, Q104.1, R256.2, R258.2, R259.2, U103.5, U104.1, U104.14
3.3V52: C157.1, C158.1, Q105.1, Q106.1, R261.2, R263.2, R264.2, U105.5, U106.1, U106.14
3.3V53: C160.1, C161.1, Q107.1, Q108.1, R266.2, R268.2, R269.2, U107.5, U108.1, U108.14
3.3V54: C163.1, C164.1, Q109.1, Q110.1, R271.2, R273.2, R274.2, U109.5, U110.1, U110.14
3.3V55: C166.1, C167.1, Q111.1, Q112.1, R276.2, R278.2, R279.2, U111.5, U112.1, U112.14
3.3V56: C169.1, C170.1, Q113.1, Q114.1, R281.2, R283.2, R284.2, U113.5, U114.1, U114.14
3.3V57: C172.1, C173.1, Q115.1, Q116.1, R286.2, R288.2, R289.2, U115.5, U116.1, U116.14
3.3V58: C175.1, C176.1, Q117.1, Q118.1, R291.2, R293.2, R294.2, U117.5, U118.1, U118.14
3.3V59: C178.1, C179.1, Q119.1, Q120.1, R296.2, R298.2, R299.2, U119.5, U120.1, U120.14
3.3V60: C181.1, C182.1, Q121.1, Q122.1, R301.2, R303.2, R304.2, U121.5, U122.1, U122.14
3.3V61: C184.1, C185.1, Q123.1, Q124.1, R306.2, R308.2, R309.2, U123.5, U124.1, U124.14
3.3V62: C187.1, C188.1, Q125.1, Q126.1, R311.2, R313.2, R314.2, U125.5, U126.1, U126.14
5V: I2C.2, JP1.3, JP1.4, JP2.3, JP2.4, U2.1, U2.3
5V1: I2C1.2, JP3.3, JP3.4, JP4.3, JP4.4, U3.1, U3.3
5V2: I2C2.2, JP5.3, JP5.4, JP6.3, JP6.4, U5.1, U5.3
5V3: I2C3.2, JP7.3, JP7.4, JP8.3, JP8.4, U7.1, U7.3
5V4: I2C4.2, JP9.3, JP9.4, JP10.3, JP10.4, U9.1, U9.3
5V5: I2C5.2, JP11.3, JP11.4, JP12.3, JP12.4, U11.1, U11.3
5V6: I2C6.2, JP13.3, JP13.4, JP14.3, JP14.4, U13.1, U13.3
5V7: I2C7.2, JP15.3, JP15.4, JP16.3, JP16.4, U15.1, U15.3
5V8: I2C8.2, JP17.3, JP17.4, JP18.3, JP18.4, U17.1, U17.3
5V9: I2C9.2, JP19.3, JP19.4, JP20.3, JP20.4, U19.1, U19.3
5V10: I2C10.2, JP21.3, JP21.4, JP22.3, JP22.4, U21.1, U21.3
5V11: I2C11.2, JP23.3, JP23.4, JP24.3, JP24.4, U23.1, U23.3
5V12: I2C12.2, JP25.3, JP25.4, JP26.3, JP26.4, U25.1, U25.3
5V13: I2C13.2, JP27.3, JP27.4, JP28.3, JP28.4, U27.1, U27.3
5V14: I2C14.2, JP29.3, JP29.4, JP30.3, JP30.4, U29.1, U29.3
5V15: I2C15.2, JP31.3, JP31.4, JP32.3, JP32.4, U31.1, U31.3
5V16: I2C16.2, JP33.3, JP33.4, JP34.3, JP34.4, U33.1, U33.3
5V17: I2C17.2, JP35.3, JP35.4, JP36.3, JP36.4, U35.1, U35.3
5V18: I2C18.2, JP37.3, JP37.4, JP38.3, JP38.4, U37.1, U37.3
5V19: I2C19.2, JP39.3, JP39.4, JP40.3, JP40.4, U39.1, U39.3
5V20: I2C20.2, JP41.3, JP41.4, JP42.3, JP42.4, U41.1, U41.3
5V21: I2C21.2, JP43.3, JP43.4, JP44.3, JP44.4, U43.1, U43.3
5V22: I2C22.2, JP45.3, JP45.4, JP46.3, JP46.4, U45.1, U45.3
5V23: I2C23.2, JP47.3, JP47.4, JP48.3, JP48.4, U47.1, U47.3
5V24: I2C24.2, JP49.3, JP49.4, JP50.3, JP50.4, U49.1, U49.3
5V25: I2C25.2, JP51.3, JP51.4, JP52.3, JP52.4, U51.1, U51.3
5V26: I2C26.2, JP53.3, JP53.4, JP54.3, JP54.4, U53.1, U53.3
5V27: I2C27.2, JP55.3, JP55.4, JP56.3, JP56.4, U55.1, U55.3
5V28: I2C28.2, JP57.3, JP57.4, JP58.3, JP58.4, U57.1, U57.3
5V29: I2C29.2, JP59.3, JP59.4, JP60.3, JP60.4, U59.1, U59.3
5V30: I2C30.2, JP61.3, JP61.4, JP62.3, JP62.4, U61.1, U61.3
5V31: I2C31.2, JP63.3, JP63.4, JP64.3, JP64.4, U63.1, U63.3
5V32: I2C32.2, JP65.3, JP65.4, JP66.3, JP66.4, U65.1, U65.3
5V33: I2C33.2, JP67.3, JP67.4, JP68.3, JP68.4, U67.1, U67.3
5V34: I2C34.2, JP69.3, JP69.4, JP70.3, JP70.4, U69.1, U69.3
5V35: I2C35.2, JP71.3, JP71.4, JP72.3, JP72.4, U71.1, U71.3
5V36: I2C36.2, JP73.3, JP73.4, JP74.3, JP74.4, U73.1, U73.3
5V37: I2C37.2, JP75.3, JP75.4, JP76.3, JP76.4, U75.1, U75.3
5V38: I2C38.2, JP77.3, JP77.4, JP78.3, JP78.4, U77.1, U77.3
5V39: I2C39.2, JP79.3, JP79.4, JP80.3, JP80.4, U79.1, U79.3
5V40: I2C40.2, JP81.3, JP81.4, JP82.3, JP82.4, U81.1, U81.3
5V41: I2C41.2, JP83.3, JP83.4, JP84.3, JP84.4, U83.1, U83.3
5V42: I2C42.2, JP85.3, JP85.4, JP86.3, JP86.4, U85.1, U85.3
5V43: I2C43.2, JP87.3, JP87.4, JP88.3, JP88.4, U87.1, U87.3
5V44: I2C44.2, JP89.3, JP89.4, JP90.3, JP90.4, U89.1, U89.3
5V45: I2C45.2, JP91.3, JP91.4, JP92.3, JP92.4, U91.1, U91.3
5V46: I2C46.2, JP93.3, JP93.4, JP94.3, JP94.4, U93.1, U93.3
5V47: I2C47.2, JP95.3, JP95.4, JP96.3, JP96.4, U95.1, U95.3
5V48: I2C48.2, JP97.3, JP97.4, JP98.3, JP98.4, U97.1, U97.3
5V49: I2C49.2, JP99.3, JP99.4, JP100.3, JP100.4, U99.1, U99.3
5V50: I2C50.2, JP101.3, JP101.4, JP102.3, JP102.4, U101.1, U101.3
5V51: I2C51.2, JP103.3, JP103.4, JP104.3, JP104.4, U103.1, U103.3
5V52: I2C52.2, JP105.3, JP105.4, JP106.3, JP106.4, U105.1, U105.3
5V53: I2C53.2, JP107.3, JP107.4, JP108.3, JP108.4, U107.1, U107.3
5V54: I2C54.2, JP109.3, JP109.4, JP110.3, JP110.4, U109.1, U109.3
5V55: I2C55.2, JP111.3, JP111.4, JP112.3, JP112.4, U111.1, U111.3
5V56: I2C56.2, JP113.3, JP113.4, JP114.3, JP114.4, U113.1, U113.3
5V57: I2C57.2, JP115.3, JP115.4, JP116.3, JP116.4, U115.1, U115.3
5V58: I2C58.2, JP117.3, JP117.4, JP118.3, JP118.4, U117.1, U117.3
5V59: I2C59.2, JP119.3, JP119.4, JP120.3, JP120.4, U119.1, U119.3
5V60: I2C60.2, JP121.3, JP121.4, JP122.3, JP122.4, U121.1, U121.3
5V61: I2C61.2, JP123.3, JP123.4, JP124.3, JP124.4, U123.1, U123.3
5V62: I2C62.2, JP125.3, JP125.4, JP126.3, JP126.4, U125.1, U125.3
ADDR: R1.1, U1.7
ADDR1: R2.1, U4.7
ADDR2: R11.1, U6.7
ADDR3: R16.1, U8.7
ADDR4: R21.1, U10.7
ADDR5: R26.1, U12.7
ADDR6: R31.1, U14.7
ADDR7: R36.1, U16.7
ADDR8: R41.1, U18.7
ADDR9: R46.1, U20.7
ADDR10: R51.1, U22.7
ADDR11: R56.1, U24.7
ADDR12: R61.1, U26.7
ADDR13: R66.1, U28.7
ADDR14: R71.1, U30.7
ADDR15: R76.1, U32.7
ADDR16: R81.1, U34.7
ADDR17: R86.1, U36.7
ADDR18: R91.1, U38.7
ADDR19: R96.1, U40.7
ADDR20: R101.1, U42.7
ADDR21: R106.1, U44.7
ADDR22: R111.1, U46.7
ADDR23: R116.1, U48.7
ADDR24: R121.1, U50.7
ADDR25: R126.1, U52.7
ADDR26: R131.1, U54.7
ADDR27: R136.1, U56.7
ADDR28: R141.1, U58.7
ADDR29: R146.1, U60.7
ADDR30: R151.1, U62.7
ADDR31: R156.1, U64.7
ADDR32: R161.1, U66.7
ADDR33: R166.1, U68.7
ADDR34: R171.1, U70.7
ADDR35: R176.1, U72.7
ADDR36: R181.1, U74.7
ADDR37: R186.1, U76.7
ADDR38: R191.1, U78.7
ADDR39: R196.1, U80.7
ADDR40: R201.1, U82.7
ADDR41: R206.1, U84.7
ADDR42: R211.1, U86.7
ADDR43: R216.1, U88.7
ADDR44: R221.1, U90.7
ADDR45: R226.1, U92.7
ADDR46: R231.1, U94.7
ADDR47: R236.1, U96.7
ADDR48: R241.1, U98.7
ADDR49: R246.1, U100.7
ADDR50: R251.1, U102.7
ADDR51: R256.1, U104.7
ADDR52: R261.1, U106.7
ADDR53: R266.1, U108.7
ADDR54: R271.1, U110.7
ADDR55: R276.1, U112.7
ADDR56: R281.1, U114.7
ADDR57: R286.1, U116.7
ADDR58: R291.1, U118.7
ADDR59: R296.1, U120.7
ADDR60: R301.1, U122.7
ADDR61: R306.1, U124.7
ADDR62: R311.1, U126.7
GND: C1.2, C2.2, C3.2, JP1.5, JP1.6, JP2.5, JP2.6, U1.5, U1.10, U1.12, U2.2
GND1: C4.2, C5.2, C6.2, JP3.5, JP3.6, JP4.5, JP4.6, U3.2, U4.5, U4.10, U4.12
GND2: C7.2, C8.2, C9.2, JP5.5, JP5.6, JP6.5, JP6.6, U5.2, U6.5, U6.10, U6.12
GND3: C10.2, C11.2, C12.2, JP7.5, JP7.6, JP8.5, JP8.6, U7.2, U8.5, U8.10, U8.12
GND4: C13.2, C14.2, C15.2, JP9.5, JP9.6, JP10.5, JP10.6, U9.2, U10.5, U10.10, U10.12
GND5: C16.2, C17.2, C18.2, JP11.5, JP11.6, JP12.5, JP12.6, U11.2, U12.5, U12.10, U12.12
GND6: C19.2, C20.2, C21.2, JP13.5, JP13.6, JP14.5, JP14.6, U13.2, U14.5, U14.10, U14.12
GND7: C22.2, C23.2, C24.2, JP15.5, JP15.6, JP16.5, JP16.6, U15.2, U16.5, U16.10, U16.12
GND8: C25.2, C26.2, C27.2, JP17.5, JP17.6, JP18.5, JP18.6, U17.2, U18.5, U18.10, U18.12
GND9: C28.2, C29.2, C30.2, JP19.5, JP19.6, JP20.5, JP20.6, U19.2, U20.5, U20.10, U20.12
GND10: C31.2, C32.2, C33.2, JP21.5, JP21.6, JP22.5, JP22.6, U21.2, U22.5, U22.10, U22.12
GND11: C34.2, C35.2, C36.2, JP23.5, JP23.6, JP24.5, JP24.6, U23.2, U24.5, U24.10, U24.12
GND12: C37.2, C38.2, C39.2, JP25.5, JP25.6, JP26.5, JP26.6, U25.2, U26.5, U26.10, U26.12
GND13: C40.2, C41.2, C42.2, JP27.5, JP27.6, JP28.5, JP28.6, U27.2, U28.5, U28.10, U28.12
GND14: C43.2, C44.2, C45.2, JP29.5, JP29.6, JP30.5, JP30.6, U29.2, U30.5, U30.10, U30.12
GND15: C46.2, C47.2, C48.2, JP31.5, JP31.6, JP32.5, JP32.6, U31.2, U32.5, U32.10, U32.12
GND16: C49.2, C50.2, C51.2, JP33.5, JP33.6, JP34.5, JP34.6, U33.2, U34.5, U34.10, U34.12
GND17: C52.2, C53.2, C54.2, JP35.5, JP35.6, JP36.5, JP36.6, U35.2, U36.5, U36.10, U36.12
GND18: C55.2, C56.2, C57.2, JP37.5, JP37.6, JP38.5, JP38.6, U37.2, U38.5, U38.10, U38.12
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

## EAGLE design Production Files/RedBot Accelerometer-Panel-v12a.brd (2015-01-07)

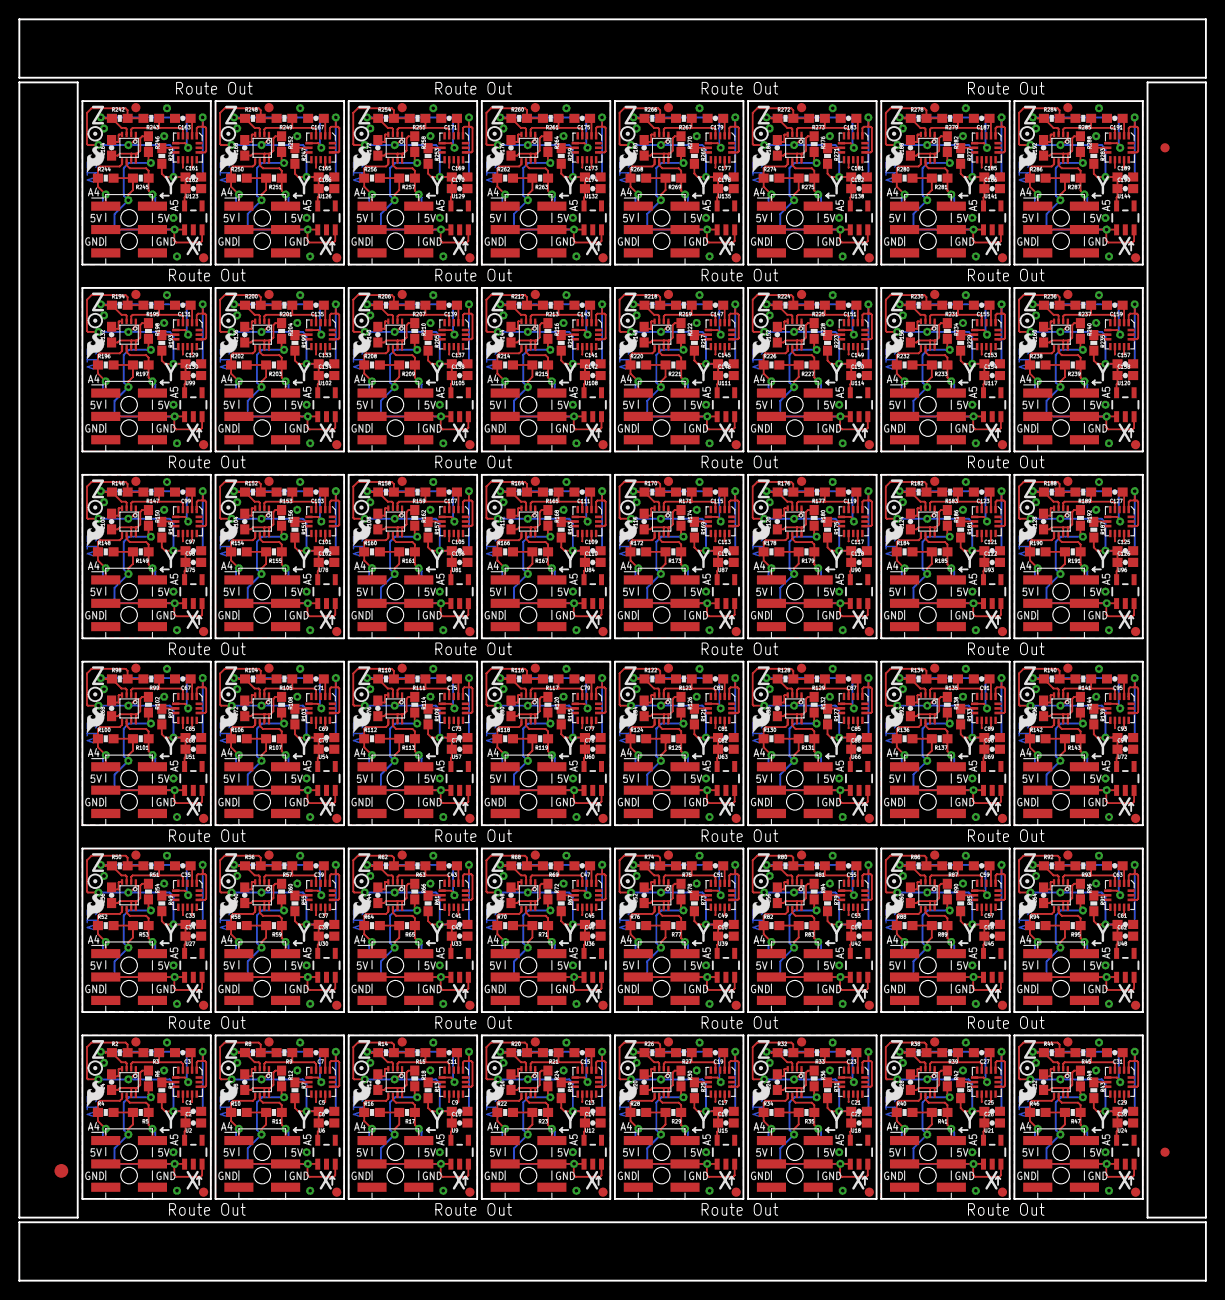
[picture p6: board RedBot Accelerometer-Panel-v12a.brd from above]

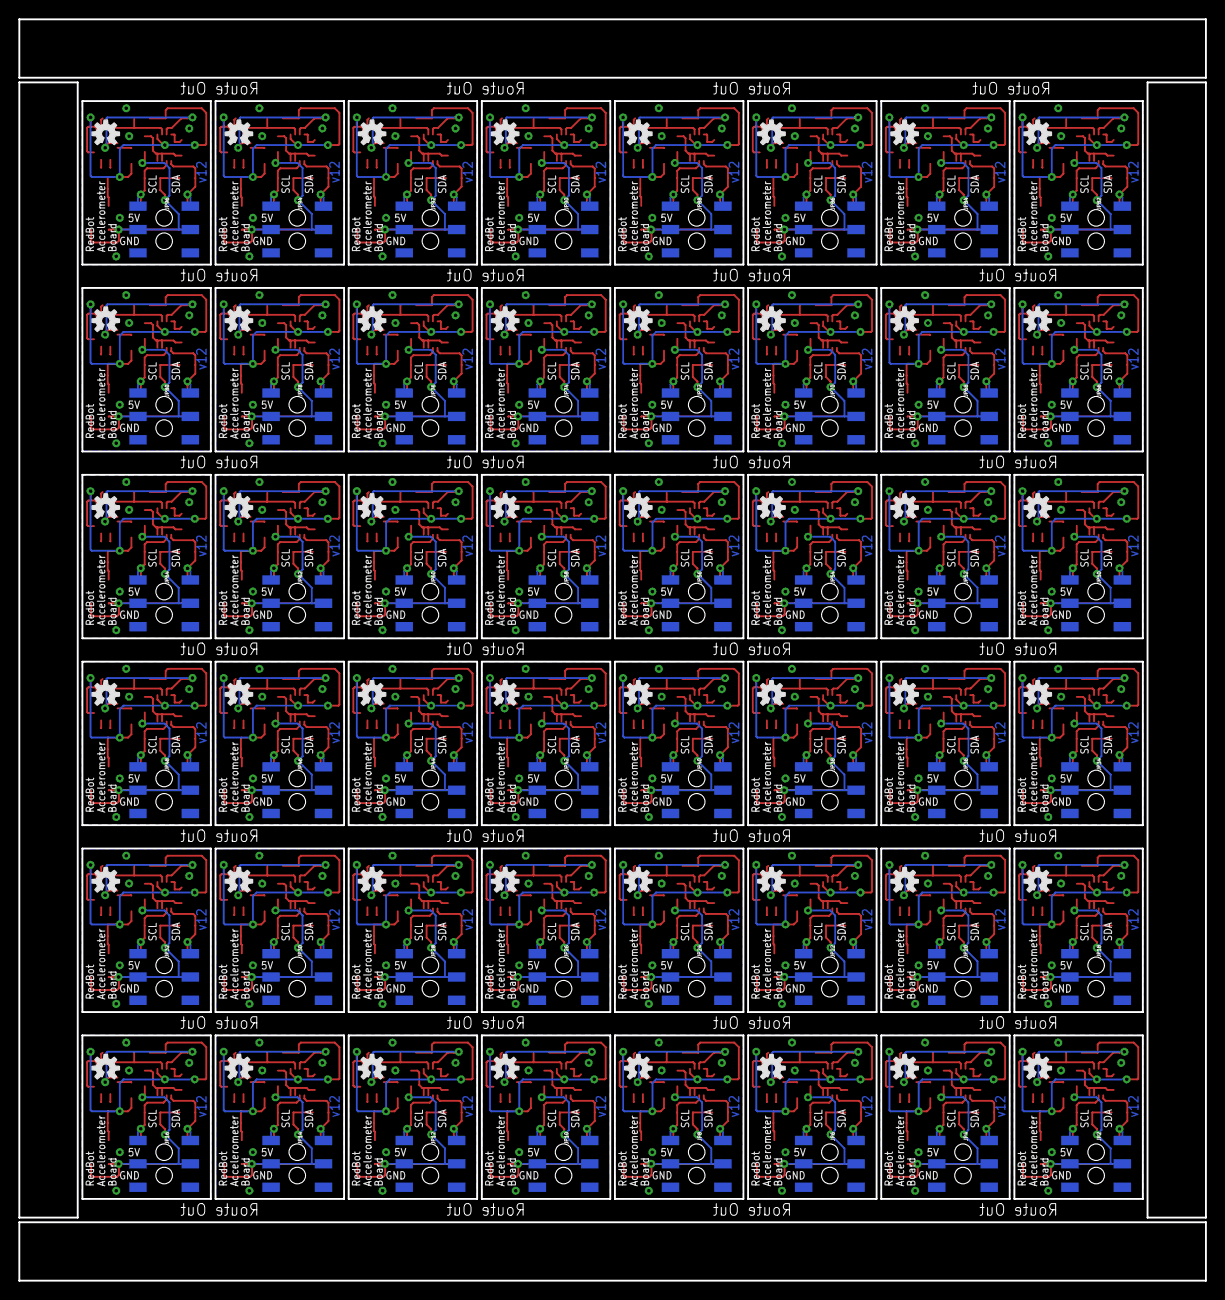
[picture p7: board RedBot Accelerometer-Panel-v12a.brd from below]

Board: 2 copper layers, 129.0 x 137.2 mm, 915 parts (96 on the bottom side), 480 nets.

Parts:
C1, C3, C4, C5, C7, C8, C9, C11, C12, C13, C15, C16, C17, C19, C20, C21, C23, C24, C25, C27, C28, C29, C31, C32, C33, C35, C36, C37, C39, C40, C41, C43, C44, C45, C47, C48, C49, C51, C52, C53, C55, C56, C57, C59, C60, C61, C63, C64, C65, C67, C68, C69, C71, C72, C73, C75, C76, C77, C79, C80, C81, C83, C84, C85, C87, C88, C89, C91, C92, C93, C95, C96, C97, C99, C100, C101, C103, C104, C105, C107, C108, C109, C111, C112, C113, C115, C116, C117, C119, C120, C121, C123, C124, C125, C127, C128, C129, C131, C132, C133, C135, C136, C137, C139, C140, C141, C143, C144, C145, C147, C148, C149, C151, C152, C153, C155, C156, C157, C159, C160, C161, C163, C164, C165, C167, C168, C169, C171, C172, C173, C175, C176, C177, C179, C180, C181, C183, C184, C185, C187, C188, C189, C191, C192: 0.1uF; 0603-CAP
C2, C6, C10, C14, C18, C22, C26, C30, C34, C38, C42, C46, C50, C54, C58, C62, C66, C70, C74, C78, C82, C86, C90, C94, C98, C102, C106, C110, C114, C118, C122, C126, C130, C134, C138, C142, C146, C150, C154, C158, C162, C166, C170, C174, C178, C182, C186, C190: 4.7uF; 0603-CAP
E$1: FIDUCIAL-1.5X3
E$2, E$3: FIDUCIAL-1X2
FID1, FID2, FID3, FID4, FID5, FID6, FID7, FID8, FID9, FID10, FID11, FID12, FID13, FID14, FID15, FID16, FID17, FID18, FID19, FID20, FID21, FID22, FID23, FID24, FID25, FID26, FID27, FID28, FID29, FID30, FID31, FID32, FID33, FID34, FID35, FID36, FID37, FID38, FID39, FID40, FID41, FID42, FID43, FID44, FID45, FID46, FID47, FID48, FID49, FID50, FID51, FID52, FID53, FID54, FID55, FID56, FID57, FID58, FID59, FID60, FID61, FID62, FID63, FID64, FID65, FID66, FID67, FID68, FID69, FID70, FID71, FID72, FID73, FID74, FID75, FID76, FID77, FID78, FID79, FID80, FID81, FID82, FID83, FID84, FID85, FID86, FID87, FID88, FID89, FID90, FID91, FID92, FID93, FID94, FID95, FID96: FIDUCIAL1X2; FIDUCIAL-1X2
JP1, JP3, JP5, JP7, JP9, JP11, JP13, JP15, JP17, JP19, JP21, JP23, JP25, JP27, JP29, JP31, JP33, JP35, JP37, JP39, JP41, JP43, JP45, JP47, JP49, JP51, JP53, JP55, JP57, JP59, JP61, JP63, JP65, JP67, JP69, JP71, JP73, JP75, JP77, JP79, JP81, JP83, JP85, JP87, JP89, JP91, JP93, JP95: 2X3_SMT_POSTS
JP2, JP4, JP6, JP8, JP10, JP12, JP14, JP16, JP18, JP20, JP22, JP24, JP26, JP28, JP30, JP32, JP34, JP36, JP38, JP40, JP42, JP44, JP46, JP48, JP50, JP52, JP54, JP56, JP58, JP60, JP62, JP64, JP66, JP68, JP70, JP72, JP74, JP76, JP78, JP80, JP82, JP84, JP86, JP88, JP90, JP92, JP94, JP96: 2X3_SMD
LOGO1, LOGO3, LOGO5, LOGO7, LOGO9, LOGO11, LOGO13, LOGO15, LOGO17, LOGO19, LOGO21, LOGO23, LOGO25, LOGO27, LOGO29, LOGO31, LOGO33, LOGO35, LOGO37, LOGO39, LOGO41, LOGO43, LOGO45, LOGO47, LOGO49, LOGO51, LOGO53, LOGO55, LOGO57, LOGO59, LOGO61, LOGO63, LOGO65, LOGO67, LOGO69, LOGO71, LOGO73, LOGO75, LOGO77, LOGO79, LOGO81, LOGO83, LOGO85, LOGO87, LOGO89, LOGO91, LOGO93, LOGO95: LOGO-SFESK; SFE-LOGO-FLAME
LOGO2, LOGO4, LOGO6, LOGO8, LOGO10, LOGO12, LOGO14, LOGO16, LOGO18, LOGO20, LOGO22, LOGO24, LOGO26, LOGO28, LOGO30, LOGO32, LOGO34, LOGO36, LOGO38, LOGO40, LOGO42, LOGO44, LOGO46, LOGO48, LOGO50, LOGO52, LOGO54, LOGO56, LOGO58, LOGO60, LOGO62, LOGO64, LOGO66, LOGO68, LOGO70, LOGO72, LOGO74, LOGO76, LOGO78, LOGO80, LOGO82, LOGO84, LOGO86, LOGO88, LOGO90, LOGO92, LOGO94, LOGO96: OSHW-LOGOS; OSHW-LOGO-S
R1, R7, R13, R19, R25, R31, R37, R43, R49, R55, R61, R67, R73, R79, R85, R91, R97, R103, R109, R115, R121, R127, R133, R139, R145, R151, R157, R163, R169, R175, R181, R187, R193, R199, R205, R211, R217, R223, R229, R235, R241, R247, R253, R259, R265, R271, R277, R283: 10k; 0603-RES
R2, R3, R4, R5, R8, R9, R10, R11, R14, R15, R16, R17, R20, R21, R22, R23, R26, R27, R28, R29, R32, R33, R34, R35, R38, R39, R40, R41, R44, R45, R46, R47, R50, R51, R52, R53, R56, R57, R58, R59, R62, R63, R64, R65, R68, R69, R70, R71, R74, R75, R76, R77, R80, R81, R82, R83, R86, R87, R88, R89, R92, R93, R94, R95, R98, R99, R100, R101, R104, R105, R106, R107, R110, R111, R112, R113, R116, R117, R118, R119, R122, R123, R124, R125, R128, R129, R130, R131, R134, R135, R136, R137, R140, R141, R142, R143, R146, R147, R148, R149, R152, R153, R154, R155, R158, R159, R160, R161, R164, R165, R166, R167, R170, R171, R172, R173, R176, R177, R178, R179, R182, R183, R184, R185, R188, R189, R190, R191, R194, R195, R196, R197, R200, R201, R202, R203, R206, R207, R208, R209, R212, R213, R214, R215, R218, R219, R220, R221, R224, R225, R226, R227, R230, R231, R232, R233, R236, R237, R238, R239, R242, R243, R244, R245, R248, R249, R250, R251, R254, R255, R256, R257, R260, R261, R262, R263, R266, R267, R268, R269, R272, R273, R274, R275, R278, R279, R280, R281, R284, R285, R286, R287: 1k; 0603-RES
R6, R12, R18, R24, R30, R36, R42, R48, R54, R60, R66, R72, R78, R84, R90, R96, R102, R108, R114, R120, R126, R132, R138, R144, R150, R156, R162, R168, R174, R180, R186, R192, R198, R204, R210, R216, R222, R228, R234, R240, R246, R252, R258, R264, R270, R276, R282, R288: 200k; 0603-RES
U1, U5, U8, U11, U14, U17, U20, U23, U26, U29, U32, U35, U38, U41, U44, U47, U50, U53, U56, U59, U62, U65, U68, U71, U74, U77, U80, U83, U86, U89, U92, U95, U98, U101, U104, U107, U110, U113, U116, U119, U122, U125, U128, U131, U134, U137, U140, U143: MMA8452QMMA8452Q-1:1; MMA8452Q-1:1
U2, U6, U9, U12, U15, U18, U21, U24, U27, U30, U33, U36, U39, U42, U45, U48, U51, U54, U57, U60, U63, U66, U69, U72, U75, U78, U81, U84, U87, U90, U93, U96, U99, U102, U105, U108, U111, U114, U117, U120, U123, U126, U129, U132, U135, U138, U141, U144: MIC5205-3.3V; SOT23-5
U3, U4, U7, U10, U13, U16, U19, U22, U25, U28, U31, U34, U37, U40, U43, U46, U49, U52, U55, U58, U61, U64, U67, U70, U73, U76, U79, U82, U85, U88, U91, U94, U97, U100, U103, U106, U109, U112, U115, U118, U121, U124, U127, U130, U133, U136, U139, U142: PCA9306; PCA9306DC-1:1

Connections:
3.3V: C1.1, C2.1, R1.2, R2.2, R3.2, U1.1, U1.14, U2.5, U3.1
3.3V1: C5.1, C6.1, R7.2, R8.2, R9.2, U4.1, U5.1, U5.14, U6.5
3.3V2: C9.1, C10.1, R13.2, R14.2, R15.2, U7.1, U8.1, U8.14, U9.5
3.3V3: C13.1, C14.1, R19.2, R20.2, R21.2, U10.1, U11.1, U11.14, U12.5
3.3V4: C17.1, C18.1, R25.2, R26.2, R27.2, U13.1, U14.1, U14.14, U15.5
3.3V5: C21.1, C22.1, R31.2, R32.2, R33.2, U16.1, U17.1, U17.14, U18.5
3.3V6: C25.1, C26.1, R37.2, R38.2, R39.2, U19.1, U20.1, U20.14, U21.5
3.3V7: C29.1, C30.1, R43.2, R44.2, R45.2, U22.1, U23.1, U23.14, U24.5
3.3V8: C33.1, C34.1, R49.2, R50.2, R51.2, U25.1, U26.1, U26.14, U27.5
3.3V9: C37.1, C38.1, R55.2, R56.2, R57.2, U28.1, U29.1, U29.14, U30.5
3.3V10: C41.1, C42.1, R61.2, R62.2, R63.2, U31.1, U32.1, U32.14, U33.5
3.3V11: C45.1, C46.1, R67.2, R68.2, R69.2, U34.1, U35.1, U35.14, U36.5
3.3V12: C49.1, C50.1, R73.2, R74.2, R75.2, U37.1, U38.1, U38.14, U39.5
3.3V13: C53.1, C54.1, R79.2, R80.2, R81.2, U40.1, U41.1, U41.14, U42.5
3.3V14: C57.1, C58.1, R85.2, R86.2, R87.2, U43.1, U44.1, U44.14, U45.5
3.3V15: C61.1, C62.1, R91.2, R92.2, R93.2, U46.1, U47.1, U47.14, U48.5
3.3V16: C65.1, C66.1, R97.2, R98.2, R99.2, U49.1, U50.1, U50.14, U51.5
3.3V17: C69.1, C70.1, R103.2, R104.2, R105.2, U52.1, U53.1, U53.14, U54.5
3.3V18: C73.1, C74.1, R109.2, R110.2, R111.2, U55.1, U56.1, U56.14, U57.5
3.3V19: C77.1, C78.1, R115.2, R116.2, R117.2, U58.1, U59.1, U59.14, U60.5
3.3V20: C81.1, C82.1, R121.2, R122.2, R123.2, U61.1, U62.1, U62.14, U63.5
3.3V21: C85.1, C86.1, R127.2, R128.2, R129.2, U64.1, U65.1, U65.14, U66.5
3.3V22: C89.1, C90.1, R133.2, R134.2, R135.2, U67.1, U68.1, U68.14, U69.5
3.3V23: C93.1, C94.1, R139.2, R140.2, R141.2, U70.1, U71.1, U71.14, U72.5
3.3V24: C97.1, C98.1, R145.2, R146.2, R147.2, U73.1, U74.1, U74.14, U75.5
3.3V25: C101.1, C102.1, R151.2, R152.2, R153.2, U76.1, U77.1, U77.14, U78.5
3.3V26: C105.1, C106.1, R157.2, R158.2, R159.2, U79.1, U80.1, U80.14, U81.5
3.3V27: C109.1, C110.1, R163.2, R164.2, R165.2, U82.1, U83.1, U83.14, U84.5
3.3V28: C113.1, C114.1, R169.2, R170.2, R171.2, U85.1, U86.1, U86.14, U87.5
3.3V29: C117.1, C118.1, R175.2, R176.2, R177.2, U88.1, U89.1, U89.14, U90.5
3.3V30: C121.1, C122.1, R181.2, R182.2, R183.2, U91.1, U92.1, U92.14, U93.5
3.3V31: C125.1, C126.1, R187.2, R188.2, R189.2, U94.1, U95.1, U95.14, U96.5
3.3V32: C129.1, C130.1, R193.2, R194.2, R195.2, U97.1, U98.1, U98.14, U99.5
3.3V33: C133.1, C134.1, R199.2, R200.2, R201.2, U100.1, U101.1, U101.14, U102.5
3.3V34: C137.1, C138.1, R205.2, R206.2, R207.2, U103.1, U104.1, U104.14, U105.5
3.3V35: C141.1, C142.1, R211.2, R212.2, R213.2, U106.1, U107.1, U107.14, U108.5
3.3V36: C145.1, C146.1, R217.2, R218.2, R219.2, U109.1, U110.1, U110.14, U111.5
3.3V37: C149.1, C150.1, R223.2, R224.2, R225.2, U112.1, U113.1, U113.14, U114.5
3.3V38: C153.1, C154.1, R229.2, R230.2, R231.2, U115.1, U116.1, U116.14, U117.5
3.3V39: C157.1, C158.1, R235.2, R236.2, R237.2, U118.1, U119.1, U119.14, U120.5
3.3V40: C161.1, C162.1, R241.2, R242.2, R243.2, U121.1, U122.1, U122.14, U123.5
3.3V41: C165.1, C166.1, R247.2, R248.2, R249.2, U124.1, U125.1, U125.14, U126.5
3.3V42: C169.1, C170.1, R253.2, R254.2, R255.2, U127.1, U128.1, U128.14, U129.5
3.3V43: C173.1, C174.1, R259.2, R260.2, R261.2, U130.1, U131.1, U131.14, U132.5
3.3V44: C177.1, C178.1, R265.2, R266.2, R267.2, U133.1, U134.1, U134.14, U135.5
3.3V45: C181.1, C182.1, R271.2, R272.2, R273.2, U136.1, U137.1, U137.14, U138.5
3.3V46: C185.1, C186.1, R277.2, R278.2, R279.2, U139.1, U140.1, U140.14, U141.5
3.3V47: C189.1, C190.1, R283.2, R284.2, R285.2, U142.1, U143.1, U143.14, U144.5
5V: JP1.3, JP1.4, JP2.3, JP2.4, R4.2, R5.2, R6.2, U2.1, U2.3
5V1: JP3.3, JP3.4, JP4.3, JP4.4, R10.2, R11.2, R12.2, U6.1, U6.3
5V2: JP5.3, JP5.4, JP6.3, JP6.4, R16.2, R17.2, R18.2, U9.1, U9.3
5V3: JP7.3, JP7.4, JP8.3, JP8.4, R22.2, R23.2, R24.2, U12.1, U12.3
5V4: JP9.3, JP9.4, JP10.3, JP10.4, R28.2, R29.2, R30.2, U15.1, U15.3
5V5: JP11.3, JP11.4, JP12.3, JP12.4, R34.2, R35.2, R36.2, U18.1, U18.3
5V6: JP13.3, JP13.4, JP14.3, JP14.4, R40.2, R41.2, R42.2, U21.1, U21.3
5V7: JP15.3, JP15.4, JP16.3, JP16.4, R46.2, R47.2, R48.2, U24.1, U24.3
5V8: JP17.3, JP17.4, JP18.3, JP18.4, R52.2, R53.2, R54.2, U27.1, U27.3
5V9: JP19.3, JP19.4, JP20.3, JP20.4, R58.2, R59.2, R60.2, U30.1, U30.3
5V10: JP21.3, JP21.4, JP22.3, JP22.4, R64.2, R65.2, R66.2, U33.1, U33.3
5V11: JP23.3, JP23.4, JP24.3, JP24.4, R70.2, R71.2, R72.2, U36.1, U36.3
5V12: JP25.3, JP25.4, JP26.3, JP26.4, R76.2, R77.2, R78.2, U39.1, U39.3
5V13: JP27.3, JP27.4, JP28.3, JP28.4, R82.2, R83.2, R84.2, U42.1, U42.3
5V14: JP29.3, JP29.4, JP30.3, JP30.4, R88.2, R89.2, R90.2, U45.1, U45.3
5V15: JP31.3, JP31.4, JP32.3, JP32.4, R94.2, R95.2, R96.2, U48.1, U48.3
5V16: JP33.3, JP33.4, JP34.3, JP34.4, R100.2, R101.2, R102.2, U51.1, U51.3
5V17: JP35.3, JP35.4, JP36.3, JP36.4, R106.2, R107.2, R108.2, U54.1, U54.3
5V18: JP37.3, JP37.4, JP38.3, JP38.4, R112.2, R113.2, R114.2, U57.1, U57.3
5V19: JP39.3, JP39.4, JP40.3, JP40.4, R118.2, R119.2, R120.2, U60.1, U60.3
5V20: JP41.3, JP41.4, JP42.3, JP42.4, R124.2, R125.2, R126.2, U63.1, U63.3
5V21: JP43.3, JP43.4, JP44.3, JP44.4, R130.2, R131.2, R132.2, U66.1, U66.3
5V22: JP45.3, JP45.4, JP46.3, JP46.4, R136.2, R137.2, R138.2, U69.1, U69.3
5V23: JP47.3, JP47.4, JP48.3, JP48.4, R142.2, R143.2, R144.2, U72.1, U72.3
5V24: JP49.3, JP49.4, JP50.3, JP50.4, R148.2, R149.2, R150.2, U75.1, U75.3
5V25: JP51.3, JP51.4, JP52.3, JP52.4, R154.2, R155.2, R156.2, U78.1, U78.3
5V26: JP53.3, JP53.4, JP54.3, JP54.4, R160.2, R161.2, R162.2, U81.1, U81.3
5V27: JP55.3, JP55.4, JP56.3, JP56.4, R166.2, R167.2, R168.2, U84.1, U84.3
5V28: JP57.3, JP57.4, JP58.3, JP58.4, R172.2, R173.2, R174.2, U87.1, U87.3
5V29: JP59.3, JP59.4, JP60.3, JP60.4, R178.2, R179.2, R180.2, U90.1, U90.3
5V30: JP61.3, JP61.4, JP62.3, JP62.4, R184.2, R185.2, R186.2, U93.1, U93.3
5V31: JP63.3, JP63.4, JP64.3, JP64.4, R190.2, R191.2, R192.2, U96.1, U96.3
5V32: JP65.3, JP65.4, JP66.3, JP66.4, R196.2, R197.2, R198.2, U99.1, U99.3
5V33: JP67.3, JP67.4, JP68.3, JP68.4, R202.2, R203.2, R204.2, U102.1, U102.3
5V34: JP69.3, JP69.4, JP70.3, JP70.4, R208.2, R209.2, R210.2, U105.1, U105.3
5V35: JP71.3, JP71.4, JP72.3, JP72.4, R214.2, R215.2, R216.2, U108.1, U108.3
5V36: JP73.3, JP73.4, JP74.3, JP74.4, R220.2, R221.2, R222.2, U111.1, U111.3
5V37: JP75.3, JP75.4, JP76.3, JP76.4, R226.2, R227.2, R228.2, U114.1, U114.3
5V38: JP77.3, JP77.4, JP78.3, JP78.4, R232.2, R233.2, R234.2, U117.1, U117.3
5V39: JP79.3, JP79.4, JP80.3, JP80.4, R238.2, R239.2, R240.2, U120.1, U120.3
5V40: JP81.3, JP81.4, JP82.3, JP82.4, R244.2, R245.2, R246.2, U123.1, U123.3
5V41: JP83.3, JP83.4, JP84.3, JP84.4, R250.2, R251.2, R252.2, U126.1, U126.3
5V42: JP85.3, JP85.4, JP86.3, JP86.4, R256.2, R257.2, R258.2, U129.1, U129.3
5V43: JP87.3, JP87.4, JP88.3, JP88.4, R262.2, R263.2, R264.2, U132.1, U132.3
5V44: JP89.3, JP89.4, JP90.3, JP90.4, R268.2, R269.2, R270.2, U135.1, U135.3
5V45: JP91.3, JP91.4, JP92.3, JP92.4, R274.2, R275.2, R276.2, U138.1, U138.3
5V46: JP93.3, JP93.4, JP94.3, JP94.4, R280.2, R281.2, R282.2, U141.1, U141.3
5V47: JP95.3, JP95.4, JP96.3, JP96.4, R286.2, R287.2, R288.2, U144.1, U144.3
ADDR: R1.1, U1.7
ADDR1: R7.1, U5.7
ADDR2: R13.1, U8.7
ADDR3: R19.1, U11.7
ADDR4: R25.1, U14.7
ADDR5: R31.1, U17.7
ADDR6: R37.1, U20.7
ADDR7: R43.1, U23.7
ADDR8: R49.1, U26.7
ADDR9: R55.1, U29.7
ADDR10: R61.1, U32.7
ADDR11: R67.1, U35.7
ADDR12: R73.1, U38.7
ADDR13: R79.1, U41.7
ADDR14: R85.1, U44.7
ADDR15: R91.1, U47.7
ADDR16: R97.1, U50.7
ADDR17: R103.1, U53.7
ADDR18: R109.1, U56.7
ADDR19: R115.1, U59.7
ADDR20: R121.1, U62.7
ADDR21: R127.1, U65.7
ADDR22: R133.1, U68.7
ADDR23: R139.1, U71.7
ADDR24: R145.1, U74.7
ADDR25: R151.1, U77.7
ADDR26: R157.1, U80.7
ADDR27: R163.1, U83.7
ADDR28: R169.1, U86.7
ADDR29: R175.1, U89.7
ADDR30: R181.1, U92.7
ADDR31: R187.1, U95.7
ADDR32: R193.1, U98.7
ADDR33: R199.1, U101.7
ADDR34: R205.1, U104.7
ADDR35: R211.1, U107.7
ADDR36: R217.1, U110.7
ADDR37: R223.1, U113.7
ADDR38: R229.1, U116.7
ADDR39: R235.1, U119.7
ADDR40: R241.1, U122.7
ADDR41: R247.1, U125.7
ADDR42: R253.1, U128.7
ADDR43: R259.1, U131.7
ADDR44: R265.1, U134.7
ADDR45: R271.1, U137.7
ADDR46: R277.1, U140.7
ADDR47: R283.1, U143.7
GND: C1.2, C2.2, C3.2, C4.2, JP1.5, JP1.6, JP2.5, JP2.6, U1.5, U1.10, U1.12, U2.2, U3.4
GND1: C5.2, C6.2, C7.2, C8.2, JP3.5, JP3.6, JP4.5, JP4.6, U4.4, U5.5, U5.10, U5.12, U6.2
GND2: C9.2, C10.2, C11.2, C12.2, JP5.5, JP5.6, JP6.5, JP6.6, U7.4, U8.5, U8.10, U8.12, U9.2
GND3: C13.2, C14.2, C15.2, C16.2, JP7.5, JP7.6, JP8.5, JP8.6, U10.4, U11.5, U11.10, U11.12, U12.2
GND4: C17.2, C18.2, C19.2, C20.2, JP9.5, JP9.6, JP10.5, JP10.6, U13.4, U14.5, U14.10, U14.12, U15.2
GND5: C21.2, C22.2, C23.2, C24.2, JP11.5, JP11.6, JP12.5, JP12.6, U16.4, U17.5, U17.10, U17.12, U18.2
GND6: C25.2, C26.2, C27.2, C28.2, JP13.5, JP13.6, JP14.5, JP14.6, U19.4, U20.5, U20.10, U20.12, U21.2
GND7: C29.2, C30.2, C31.2, C32.2, JP15.5, JP15.6, JP16.5, JP16.6, U22.4, U23.5, U23.10, U23.12, U24.2
GND8: C33.2, C34.2, C35.2, C36.2, JP17.5, JP17.6, JP18.5, JP18.6, U25.4, U26.5, U26.10, U26.12, U27.2
GND9: C37.2, C38.2, C39.2, C40.2, JP19.5, JP19.6, JP20.5, JP20.6, U28.4, U29.5, U29.10, U29.12, U30.2
GND10: C41.2, C42.2, C43.2, C44.2, JP21.5, JP21.6, JP22.5, JP22.6, U31.4, U32.5, U32.10, U32.12, U33.2
GND11: C45.2, C46.2, C47.2, C48.2, JP23.5, JP23.6, JP24.5, JP24.6, U34.4, U35.5, U35.10, U35.12, U36.2
GND12: C49.2, C50.2, C51.2, C52.2, JP25.5, JP25.6, JP26.5, JP26.6, U37.4, U38.5, U38.10, U38.12, U39.2
GND13: C53.2, C54.2, C55.2, C56.2, JP27.5, JP27.6, JP28.5, JP28.6, U40.4, U41.5, U41.10, U41.12, U42.2
GND14: C57.2, C58.2, C59.2, C60.2, JP29.5, JP29.6, JP30.5, JP30.6, U43.4, U44.5, U44.10, U44.12, U45.2
GND15: C61.2, C62.2, C63.2, C64.2, JP31.5, JP31.6, JP32.5, JP32.6, U46.4, U47.5, U47.10, U47.12, U48.2
GND16: C65.2, C66.2, C67.2, C68.2, JP33.5, JP33.6, JP34.5, JP34.6, U49.4, U50.5, U50.10, U50.12, U51.2
GND17: C69.2, C70.2, C71.2, C72.2, JP35.5, JP35.6, JP36.5, JP36.6, U52.4, U53.5, U53.10, U53.12, U54.2
GND18: C73.2, C74.2, C75.2, C76.2, JP37.5, JP37.6, JP38.5, JP38.6, U55.4, U56.5, U56.10, U56.12, U57.2
GND19: C77.2, C78.2, C79.2, C80.2, JP39.5, JP39.6, JP40.5, JP40.6, U58.4, U59.5, U59.10, U59.12, U60.2
GND20: C81.2, C82.2, C83.2, C84.2, JP41.5, JP41.6, JP42.5, JP42.6, U61.4, U62.5, U62.10, U62.12, U63.2
GND21: C85.2, C86.2, C87.2, C88.2, JP43.5, JP43.6, JP44.5, JP44.6, U64.4, U65.5, U65.10, U65.12, U66.2
GND22: C89.2, C90.2, C91.2, C92.2, JP45.5, JP45.6, JP46.5, JP46.6, U67.4, U68.5, U68.10, U68.12, U69.2
GND23: C93.2, C94.2, C95.2, C96.2, JP47.5, JP47.6, JP48.5, JP48.6, U70.4, U71.5, U71.10, U71.12, U72.2
GND24: C97.2, C98.2, C99.2, C100.2, JP49.5, JP49.6, JP50.5, JP50.6, U73.4, U74.5, U74.10, U74.12, U75.2
GND25: C101.2, C102.2, C103.2, C104.2, JP51.5, JP51.6, JP52.5, JP52.6, U76.4, U77.5, U77.10, U77.12, U78.2
GND26: C105.2, C106.2, C107.2, C108.2, JP53.5, JP53.6, JP54.5, JP54.6, U79.4, U80.5, U80.10, U80.12, U81.2
GND27: C109.2, C110.2, C111.2, C112.2, JP55.5, JP55.6, JP56.5, JP56.6, U82.4, U83.5, U83.10, U83.12, U84.2
GND28: C113.2, C114.2, C115.2, C116.2, JP57.5, JP57.6, JP58.5, JP58.6, U85.4, U86.5, U86.10, U86.12, U87.2
GND29: C117.2, C118.2, C119.2, C120.2, JP59.5, JP59.6, JP60.5, JP60.6, U88.4, U89.5, U89.10, U89.12, U90.2
GND30: C121.2, C122.2, C123.2, C124.2, JP61.5, JP61.6, JP62.5, JP62.6, U91.4, U92.5, U92.10, U92.12, U93.2
GND31: C125.2, C126.2, C127.2, C128.2, JP63.5, JP63.6, JP64.5, JP64.6, U94.4, U95.5, U95.10, U95.12, U96.2
GND32: C129.2, C130.2, C131.2, C132.2, JP65.5, JP65.6, JP66.5, JP66.6, U97.4, U98.5, U98.10, U98.12, U99.2
GND33: C133.2, C134.2, C135.2, C136.2, JP67.5, JP67.6, JP68.5, JP68.6, U100.4, U101.5, U101.10, U101.12, U102.2
GND34: C137.2, C138.2, C139.2, C140.2, JP69.5, JP69.6, JP70.5, JP70.6, U103.4, U104.5, U104.10, U104.12, U105.2
GND35: C141.2, C142.2, C143.2, C144.2, JP71.5, JP71.6, JP72.5, JP72.6, U106.4, U107.5, U107.10, U107.12, U108.2
GND36: C145.2, C146.2, C147.2, C148.2, JP73.5, JP73.6, JP74.5, JP74.6, U109.4, U110.5, U110.10, U110.12, U111.2
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

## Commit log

2013-03-08 v01 files for protos.
    [RedBot Accelerometer.brd, RedBot Accelerometer.sch]
2013-03-08 Add some part info for BOM purposes.
    [RedBot Accelerometer.brd, RedBot Accelerometer.sch]
2013-05-15 Advance to rev 10 for release - added pin numbers for alignment to top silk - change revision numbers
    [RedBot Accelerometer.brd, RedBot Accelerometer.sch]
2013-05-17 Production readied
    added fiducial references & created panel for manufacture
    [RedBot Accelerometer Panel v10.brd, RedBot Accelerometer.brd, RedBot Accelerometer.sch]
2013-10-22 Rev for v11 protos
    [RedBot Accelerometer.brd, RedBot Accelerometer.sch]
2013-11-26 added fiducials to board
    [RedBot Accelerometer.brd, RedBot Accelerometer.sch]
2013-11-26 created panel
    [RedBot Accelerometer-Panel-v11.brd]
2014-05-15 Added 1:1 for PCA and Accel , 0603 update
    [RedBot Accelerometer.brd, RedBot Accelerometer.sch]
2014-06-19 added regular fiducial to board, deleted old panel
    [RedBot Accelerometer-Panel-v11.brd, RedBot Accelerometer.brd, RedBot Accelerometer.sch]
2014-06-19 created panel v12
    [RedBot Accelerometer-Panel-v12.brd]
2014-08-13 Deleting v10 panel from production files
    [RedBot Accelerometer Panel v10.brd]
2014-08-13 Fixing board files
    [RedBot Accelerometer.brd, RedBot Accelerometer.sch]
2014-09-09 Fixing version numbers
    [RedBot Accelerometer.brd, RedBot Accelerometer.sch]
2015-01-07 changed fids from micro to regular
    [RedBot Accelerometer.brd, RedBot Accelerometer.sch]
2015-01-07 created panel v12a
    this panel allows for better depanelization of the boards
    [RedBot Accelerometer-Panel-v12a.brd]
2015-09-08 created large v12a panel
    [RedBot Accelerometer-Panel-v12.brd, RedBot Accelerometer-Panel-v12a.brd]
2015-09-21 added bottom side panel fiducials
    [RedBot Accelerometer-Panel-v12a.brd]
2020-05-27 pushing v14
    [RedBot Accelerometer.brd, RedBot Accelerometer.sch]
2020-05-27 updating old packages
    [RedBot Accelerometer.brd, RedBot Accelerometer.sch]
2020-05-27 post-review changes
    [RedBot Accelerometer.brd, RedBot Accelerometer.sch]

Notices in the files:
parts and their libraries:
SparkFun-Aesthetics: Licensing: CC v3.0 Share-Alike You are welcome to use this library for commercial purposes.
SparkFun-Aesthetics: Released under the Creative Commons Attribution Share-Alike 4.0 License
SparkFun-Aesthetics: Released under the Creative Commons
